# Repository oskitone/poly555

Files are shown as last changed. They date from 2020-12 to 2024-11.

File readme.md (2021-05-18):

# POLY555 Synth

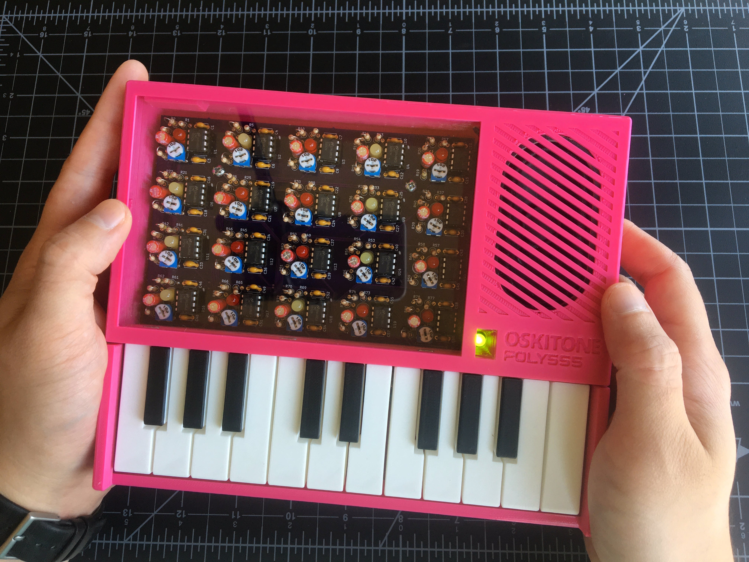
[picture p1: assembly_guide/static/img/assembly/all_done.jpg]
A finished POLY555


The POLY555 is a _polyphonic_, analog, square wave synth based on the _555_ timer chip.

**Demo:** [https://vimeo.com/487720782](https://vimeo.com/487720782)<br />
**Purchase a kit:** [https://www.oskitone.com/product/poly555-synth-diy-kit](https://www.oskitone.com/product/poly555-synth-diy-kit)<br />
**Assembly Guide:** [https://oskitone.github.io/poly555/](https://oskitone.github.io/poly555/)<br />
**Blog post:** [https://blog.tommy.sh/posts/poly555-synth/](https://blog.tommy.sh/posts/poly555-synth/)

## Code

This repo contains:

1. The [kicad](kicad) project for the PCB
2. The [openscad](openscad) code for generating the models for 3D-printing
3. The [assembly_guide](assembly_guide) code for, you guessed it, generating the [Assembly Guide](https://oskitone.github.io/poly555/)

### License

Designed by Oskitone. Please support future synth projects by purchasing from [Oskitone](https://www.oskitone.com/).

Creative Commons Attribution/Share-Alike, all text above must be included in any redistribution. See license.txt for additional details.

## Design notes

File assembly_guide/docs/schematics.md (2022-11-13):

---
id: schematics
title: "Appendix: Schematics"
description: POLY555 electronics schematic
sidebar_label: Schematics
image: /img/schematics/poly_555.svg
---

POLY555 schematic

555 sheet schematic

Enumerated sheet schematics here: [https://github.com/oskitone/poly555](https://github.com/oskitone/poly555)

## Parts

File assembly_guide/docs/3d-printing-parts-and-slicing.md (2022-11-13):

---
id: 3d-printing-parts-and-slicing
title: 3D-Printing Parts and Slicing
sidebar_label: Parts and Slicing
description: Downloading and slicing the POLY555 parts for your 3D-printer
image: /img/assembly/all_done.jpg
---

:::note
If you bought the kit with the 3D-printed parts included, you can skip this part!
:::

## Download 3D Models

The POLY555's models are hosted on Thingiverse at [https://www.thingiverse.com/thing:4676728/files](https://www.thingiverse.com/thing:4676728/files).

Download them and then come on back here!

## Parts

There are five parts you'll need to print:

1. **Enclosure top:**
   The enclosure's top with window, speaker grill, LED cavity, and branding engraving
2. **Enclosure bottom:**
   The biggest piece! The PCB mounts onto this.
3. **Keys:**
   The piano keys. This needs to be printed in two colors, see below.
4. **Mounting rail:**
   This mounting rail piece will sit between the PCB and the keys.
5. **Volume wheel:**
   And the volume wheel fits onto a potentiometer and is exposed on the enclosure's side.

### Reduced test case

Wondering what that sixth file called "reduced_test_case" is for?

This is optional but helpful for confirming your printer and slicer will be able to print the full POLY555 and have it assemble as expected. It takes about 30min.

If the test case's two pieces are difficult to fit together successfully after printing, revisit your slicer settings and ensure the printer is calibrated. Repeat until successful.

## Slicing recommendations

| Piece | Layer height | Color change | Print time |
| --- | --- | --- | --- |
| **Enclosure top** | .2mm | n/a | 4hr |
| **Enclosure bottom** | .2mm | n/a | 8hr 30min  |
| **Keys** | .2mm | 16.8mm | 7hr |
| **Mounting rail** | .2mm | n/a | 30min |
| **Volume wheel** | .2mm | n/a | 10min |

**Notes:**

- Models assume Fused Deposition Modeling with a standard .4mm nozzle. Using a bigger nozzle will likely result in a loss of detail and possibly missing internal walls.
- You may find the bottoms of the keys stick together because the plastic has expanded too far into the gap between them. See if your slicer has a setting called something like ["Elephant foot compensation"](https://help.prusa3d.com/en/article/elephant-foot-compensation_114487). Otherwise you'll need to carefully cut off the excess plastic with a utility knife.
- The 3D-printed parts were designed using PLA. Other filament types like ABS are not recommended and will likely have fit or tolerance issues. (If you find that you need to drill or file your prints, that's a good sign there'll be other problems too.)
- Any supports the models need they'll already have, they'll already be rotated to the correct orientation for printing, and they shouldn't need brims. Brims on the keys, in fact, could cause warping on removal.
- The enclosure pieces are big and may warp off the bed plate without good adhesion. I tend to use a lot of glue on the bed and stay away from plastics that shrink. _Watch the first couple layers of these while printing, especially around the text engravings -- if you see bad adhesion, stop the print to remedy the situation and start again._
- If the prints aren't fitting together well, check to see that the corners aren't bulging. We should see clean, sharp edges on the mounting rail and the keys' mount. See if your slicer has settings for "coasting" or "linear advance."

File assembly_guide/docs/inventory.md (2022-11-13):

---
id: inventory
title: Inventory
sidebar_label: Inventory
description: Inventory for the POLY555 kit and what you'll need to assemble it
image: /img/kit.jpg
---

## What's Included in the Kit

:::note
While the values of the components and the layout of the PCB won't change, they may vary in appearance (ie, changing the brand of caps, different color/silkscreen PCB, wire colors, etc), so your kit's parts may look slightly different than what's pictured throughout the guide. That's just fine! Everything will work the same.
:::

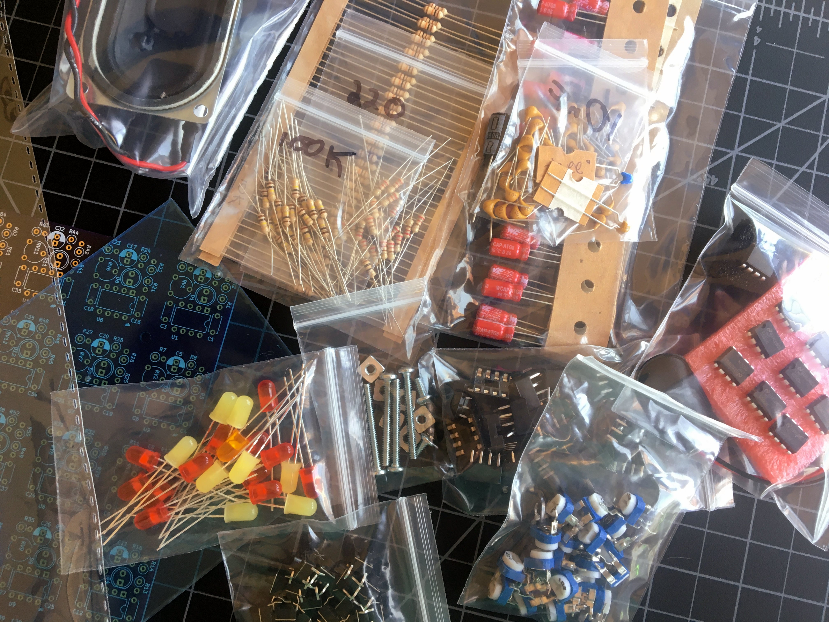
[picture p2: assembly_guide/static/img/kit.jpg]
The POLY555 DIY Kit


- **Printed circuit board (PCB):** 1
- **Plexiglass window pane:** 1
- **Electronics components:** 255 pieces total!
  - **9v snap, chips, switch:** 24
  - **Capacitors:** 64
  - **IC chip sockets:** 21
  - **LEDs:** 3 colors, 21 total
  - **Resistors:** 83
  - **Speaker:** 1
  - **Tactile switches:** 20
  - **Trim potentiometers:** 21
- **Nuts and bolts:** 12

### Not Using the Kit?

If you're going the full open-source route and gathering all the parts by yourself, head over to the [POLY555 from Scratch](poly555-from-scratch.md) appendix, then come back here when you're done.

## What You'll Need

You'll need the following tools to assemble your POLY555:

### Required

- Soldering iron and solder for electronics
- Wire stripper or cutters
- Philips and flathead screwdrivers
- Chromatic instrument tuner, phone app, or an [online tuner](https://www.google.com/search?q=online+instrument+tuner)
- Utility knife
- School glue
- 9v battery

### Recommended

- Multimeter for debugging
- PCB vice or “helping hands” holder
- “Solder sucker” or desoldering braid
- Tweezers or “dentist’s tools” for working with small components
- Windex
- Patience, patience, patience

:::tip
Give yourself plenty of time to put this together, at least 5 hours. There are a lot of components and things to solder!

I like to spread it out throughout the day and take lots of breaks!
:::

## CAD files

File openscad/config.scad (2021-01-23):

SHOW_ENCLOSURE_BOTTOM = true;
SHOW_BATTERY = true;
SHOW_SPEAKER = true;
SHOW_SWITCH = true;
SHOW_PCB = true;
SHOW_VOLUME_WHEEL = true;
SHOW_MOUNTING_RAIL = true;
SHOW_KEYS = true;
SHOW_ENCLOSURE_TOP = true;
SHOW_WINDOW_PANE = false;
SHOW_PENCIL_STAND_PENCIL = false;

USE_PENCIL_STAND_DISPLAY_ANGLE = false;

ANIMATE_VISUALIZED_PLASTIC_TOLERANCE_WEIGHT = false;

QUICK_PREVIEW = true;
CROSS_SECTION = undef;
ECHO_DIMENSIONS = true;
FLIP_VERTICALLY = false;
REDUCED_TEST_CASE = false;

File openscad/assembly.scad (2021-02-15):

include <config.scad>;
include <lib/values.scad>;

use <lib/basic_shapes.scad>;
use <lib/battery.scad>;
use <lib/breakaway_support.scad>;
use <lib/diagonal_grill.scad>;
use <lib/enclosure.scad>;
use <lib/engraving.scad>;
use <lib/keys.scad>;
use <lib/mount_stilt.scad>;
use <lib/mounting_rail.scad>;
use <lib/nut_lock.scad>;
use <lib/pcb.scad>;
use <lib/pencil_stand.scad>;
use <lib/speaker.scad>;
use <lib/supportless_screw_cavity.scad>;
use <lib/switch.scad>;
use <lib/utils.scad>;

module assembly(
    key_gutter = 1,
    accidental_key_recession = 2,
    natural_key_exposed_height = 3,
    accidental_key_extra_height = 3,

    enclosure_wall = 2.4,
    enclosure_floor_ceiling = 1.8,
    enclosure_inner_wall = 1.2,
    enclosure_minimum_wall = .6,
    enclosure_fillet = 2,
    enclosure_rounding = 24,
    enclosure_lip = .8,
    enclosure_lip_height = LIP_BOX_DEFAULT_LIP_HEIGHT,
    enclosure_lip_clearance = .2,

    engraving_depth = .8,
    engraving_chamfer = .2,

    components_to_window_clearance = 2,
    speaker_to_battery_clearance = .4,
    exposed_switch_clearance = 1,
    exposed_screw_head_clearance = .4,

    mount_length = 6,
    cantilever_length = 3,
    cantilever_mount_height = 3,
    cantilever_height = 1,

    tolerance = .1,

    keys_count = 20,
    starting_natural_key_index = 3,
    key_travel = 2, // TODO: refine

    // Adjust from 0 to 1 to see possible plastic dimensions from manufacturer
    visualized_plastic_tolerance_weight = .5,
    animate_visualized_plastic_tolerance_weight = false,

    volume_wheel_exposure = 1,
    volume_wheel_cap_height = 1,
    volume_wheel_grip_size = 1.5,
    volume_wheel_vertical_clearance = .4,
    volume_wheel_brace_clearance = .2,

    pencil_stand_display_angle = 65,
    use_pencil_stand_display_angle = true,

    show_enclosure_bottom = true,
    show_battery = true,
    show_speaker = true,
    show_switch = true,
    show_pcb = true,
    show_volume_wheel = true,
    show_mounting_rail = true,
    show_keys = true,
    show_enclosure_top = true,
    show_window_pane = false,
    show_pencil_stand_pencil = true,

    enclosure_color = undef,
    enclosure_opacity = .75,
    pcb_color = "purple",
    pcb_opacity = .75,
    natural_key_color = "white",
    accidental_key_color = "black",
    key_opacity = .75,

    quick_preview = false,
    cross_section = undef,
    echo_dimensions = true,
    flip_vertically = false,
    reduced_test_case = false
) {
    e = 0.0145;
    plot = PCB_BUTTONS[1][0] - PCB_BUTTONS[0][0];
    enclosure_gutter = mount_length;

    keys_back_gutter = tolerance * 2;
    cantilever_recession = cantilever_length - keys_back_gutter;

    natural_key_width = plot * 2 - key_gutter;
    natural_key_length = natural_key_width * 4
        - (cantilever_length - cantilever_recession) - mount_length;

    mount_width= get_keys_total_width(
        count = keys_count,
        starting_note_index =
            get_starting_note_index(starting_natural_key_index),
        natural_width = natural_key_width,
        gutter = key_gutter
    );
    mount_height = BUTTON_HEIGHT;

    mounted_keys_total_length = natural_key_length
        + (cantilever_length - cantilever_recession)
        + mount_length;

    keys_mount_end_on_pcb = BOTTOM_MOUNTED_PCB_HOLES[0][1] +  mount_length / 2;
    keys_y_over_pcb = mounted_keys_total_length - keys_mount_end_on_pcb;
    keys_from_pcb_x_offset = PCB_BUTTONS[0][0] - BUTTON_WIDTH / 2 - plot + key_gutter / 2;
    keys_cavity_length = natural_key_length + key_gutter + keys_back_gutter;
    keys_and_bumper_cavity_length = keys_cavity_length + enclosure_gutter
        - key_gutter;

    mount_hole_xs = [
        BOTTOM_MOUNTED_PCB_HOLES[0][0] - keys_from_pcb_x_offset,
        BOTTOM_MOUNTED_PCB_HOLES[1][0] - keys_from_pcb_x_offset,
        BOTTOM_MOUNTED_PCB_HOLES[2][0] - keys_from_pcb_x_offset,
        BOTTOM_MOUNTED_PCB_HOLES[3][0] - keys_from_pcb_x_offset,
    ];

    window_y_extension = PCB_COMPONENTS_Y - keys_mount_end_on_pcb;
    pcb_x = enclosure_gutter - keys_from_pcb_x_offset;
    pcb_y = mounted_keys_total_length - keys_mount_end_on_pcb + enclosure_gutter;
    pcb_z = enclosure_floor_ceiling + max(
        MOUNT_STILT_MINIMUM_HEIGHT,
        SWITCH_BASE_HEIGHT + SWITCH_ACTUATOR_HEIGHT
            - enclosure_floor_ceiling + exposed_switch_clearance
    );
    pcb_stilt_height = pcb_z - enclosure_floor_ceiling;

    enclosure_width = reduced_test_case
        ? 30 // arbitrary
        : enclosure_gutter * 2 + mount_width;
    enclosure_length = pcb_y + keys_mount_end_on_pcb
        + PCB_COMPONENTS_LENGTH + window_y_extension * 2
        + enclosure_gutter;

    enclosure_height = enclosure_floor_ceiling * 2 + max(
        pcb_stilt_height + PCB_HEIGHT + PCB_COMPONENTS_HEIGHT
            + WINDOW_PANE_HEIGHT + components_to_window_clearance,
        SPEAKER_HEIGHT - SPEAKER_MAGNET_HEIGHT + BATTERY_HEIGHT
            + speaker_to_battery_clearance
    );
    enclosure_bottom_height =
        get_volume_wheel_z(
            cap_height = volume_wheel_cap_height,
            pcb_z = pcb_z,
            pcb_height = PCB_HEIGHT,
            pot_height = POT_HEIGHT,
            head_height = TRIMPOT_KNOB_HEAD_HEIGHT
        )
        + get_volume_wheel_total_height(volume_wheel_cap_height)
        + volume_wheel_vertical_clearance;
    enclosure_top_height = enclosure_height - enclosure_bottom_height;

    key_height = enclosure_height - pcb_stilt_height - enclosure_floor_ceiling
        - PCB_HEIGHT - mount_height - accidental_key_extra_height
        - accidental_key_recession;
    keys_x = pcb_x + keys_from_pcb_x_offset;
    assert(keys_x == enclosure_gutter, "keys_x should equal enclosure_gutter");
    keys_y = pcb_y
        - natural_key_length
        - (cantilever_length - cantilever_recession)
        + keys_mount_end_on_pcb
        - mount_length;
    keys_z = pcb_z + PCB_HEIGHT + BUTTON_HEIGHT;
    key_mounting_rail_x = enclosure_wall + tolerance * 2;
    key_mounting_rail_y = pcb_y + keys_mount_end_on_pcb - mount_length;

    battery_x = enclosure_width - BATTERY_WIDTH - enclosure_wall - tolerance;
    battery_y = enclosure_length - enclosure_wall - BATTERY_LENGTH - tolerance;

    switch_x = pcb_x + PCB_SWITCH_X;
    switch_y = pcb_y + PCB_SWITCH_Y;
    switch_z = pcb_z;
    switch_exposure_height = switch_z - SWITCH_BASE_HEIGHT;

    window_and_side_panel_gutter = enclosure_gutter - key_gutter;

    window_cavity_width = PCB_COMPONENTS_WIDTH +
        ((pcb_x + PCB_COMPONENTS_X) - window_and_side_panel_gutter) * 2;
    window_cavity_length = PCB_COMPONENTS_LENGTH + window_y_extension * 2;
    window_cavity_y = pcb_y + PCB_COMPONENTS_Y - window_y_extension;

    // Pane dimensions are average between +/- PLASTICS_TOLERANCE
    window_pane_x = enclosure_wall + tolerance;
    window_pane_y = pcb_y + keys_mount_end_on_pcb - tolerance
        - (mount_length - PCB_MOUNT_HOLE_DIAMETER) / 2;
    window_pane_z = enclosure_height - enclosure_floor_ceiling
        - WINDOW_PANE_HEIGHT;
    window_pane_max_width = window_cavity_width + window_pane_x * 2;
    window_pane_width = window_pane_max_width - PLASTICS_TOLERANCE;
    window_pane_max_length = enclosure_length - enclosure_wall - window_pane_y
        - tolerance;
    window_pane_length = window_pane_max_length - PLASTICS_TOLERANCE;

    side_panel_width = enclosure_width
        - window_and_side_panel_gutter * 3
        - window_cavity_width;
    side_panel_x = enclosure_width - side_panel_width - window_and_side_panel_gutter;
    side_panel_y = key_mounting_rail_y + mount_length;
    side_panel_length = enclosure_length - enclosure_gutter - side_panel_y;

    volume_wheel_diameter = (enclosure_width - (pcb_x + PCB_VOLUME_WHEEL_X)) * 2;

    branding_length = ((pcb_y + PCB_LED_Y) - side_panel_y) * 2;
    speaker_grill_length = side_panel_length - branding_length - enclosure_gutter;
    speaker_grill_y = side_panel_y + side_panel_length - speaker_grill_length;

    speaker_x = side_panel_x + side_panel_width / 2;
    speaker_y = speaker_grill_y + (speaker_grill_length - SPEAKER_LENGTH) / 2
        + SPEAKER_LENGTH / 2;
    speaker_z = enclosure_height - enclosure_floor_ceiling - SPEAKER_HEIGHT;

    aligner_width = enclosure_inner_wall;

    if (echo_dimensions) {
        echo(
            "Enclosure dimensions",
            [enclosure_width, enclosure_length, enclosure_height]
        );
        echo(
            "Window cavity dimensions",
            [window_cavity_width, window_cavity_length]
        );
        echo(
            "Window pane dimensions",
            [window_pane_width, window_pane_length]
        );
    }

    module _keys_hitch_endstop(
        clearance = .4,
        coverage = 2,
        bar_height = 1,

        cavity = false,
        cavity_key_floor = 2,
        cavity_clearance = tolerance * 4 // intentionally loose
    ) {
        xy = enclosure_wall - e;
        bar_z = keys_z + cavity_key_floor;
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

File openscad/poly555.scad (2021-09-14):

include <config.scad>;
include <lib/values.scad>;

use <lib/basic_shapes.scad>;
use <lib/battery.scad>;
use <lib/breakaway_support.scad>;
use <lib/diagonal_grill.scad>;
use <lib/enclosure.scad>;
use <lib/engraving.scad>;
use <lib/keys.scad>;
use <lib/mount_stilt.scad>;
use <lib/mounting_rail.scad>;
use <lib/nut_lock.scad>;
use <lib/pcb.scad>;
use <lib/pencil_stand.scad>;
use <lib/screw_head_exposures.scad>;
use <lib/speaker.scad>;
use <lib/switch.scad>;
use <lib/utils.scad>;

module poly555(
    key_gutter = 1,
    accidental_key_recession = 2,
    natural_key_exposed_height = 3,
    accidental_key_extra_height = 3,

    enclosure_wall = 2.4,
    enclosure_floor_ceiling = 1.8,
    enclosure_inner_wall = 1.2,
    enclosure_minimum_wall = .6,
    enclosure_fillet = 2,
    enclosure_rounding = 24,
    enclosure_lip = .8,
    enclosure_lip_height = LIP_BOX_DEFAULT_LIP_HEIGHT,
    enclosure_lip_clearance = .2,

    engraving_depth = .8,
    engraving_chamfer = .2,

    components_to_window_clearance = 2,
    speaker_to_battery_clearance = .4,
    exposed_switch_clearance = 1,
    exposed_screw_head_clearance = .4,

    mount_length = 6,
    cantilever_length = 3,
    cantilever_mount_height = 3,
    cantilever_height = 1,

    tolerance = .1,

    keys_count = 20,
    starting_natural_key_index = 3,
    key_travel = 2, // TODO: refine

    // Adjust from 0 to 1 to see possible plastic dimensions from manufacturer
    visualized_plastic_tolerance_weight = .5,
    animate_visualized_plastic_tolerance_weight = false,

    volume_wheel_exposure = 1,
    volume_wheel_cap_height = 1,
    volume_wheel_grip_size = 1.5,
    volume_wheel_vertical_clearance = .4,
    volume_wheel_brace_clearance = .2,

    pencil_stand_display_angle = 65,
    use_pencil_stand_display_angle = true,

    show_enclosure_bottom = true,
    show_battery = true,
    show_speaker = true,
    show_switch = true,
    show_pcb = true,
    show_volume_wheel = true,
    show_mounting_rail = true,
    show_keys = true,
    show_enclosure_top = true,
    show_window_pane = false,
    show_pencil_stand_pencil = true,

    enclosure_color = undef,
    enclosure_opacity = .75,
    pcb_color = "purple",
    pcb_opacity = .75,
    natural_key_color = "white",
    accidental_key_color = "black",
    key_opacity = .75,

    quick_preview = false,
    cross_section = undef,
    echo_dimensions = true,
    flip_vertically = false,
    reduced_test_case = false
) {
    e = 0.0145;
    plot = PCB_BUTTONS[1][0] - PCB_BUTTONS[0][0];
    enclosure_gutter = mount_length;

    keys_back_gutter = tolerance * 2;
    cantilever_recession = cantilever_length - keys_back_gutter;

    natural_key_width = plot * 2 - key_gutter;
    natural_key_length = natural_key_width * 4
        - (cantilever_length - cantilever_recession) - mount_length;

    mount_width= get_keys_total_width(
        count = keys_count,
        starting_note_index =
            get_starting_note_index(starting_natural_key_index),
        natural_width = natural_key_width,
        gutter = key_gutter
    );
    mount_height = BUTTON_HEIGHT;

    mounted_keys_total_length = natural_key_length
        + (cantilever_length - cantilever_recession)
        + mount_length;

    keys_mount_end_on_pcb = BOTTOM_MOUNTED_PCB_HOLES[0][1] +  mount_length / 2;
    keys_y_over_pcb = mounted_keys_total_length - keys_mount_end_on_pcb;
    keys_from_pcb_x_offset = PCB_BUTTONS[0][0] - BUTTON_WIDTH / 2 - plot + key_gutter / 2;
    keys_cavity_length = natural_key_length + key_gutter + keys_back_gutter;
    keys_and_bumper_cavity_length = keys_cavity_length + enclosure_gutter
        - key_gutter;

    mount_hole_xs = [
        BOTTOM_MOUNTED_PCB_HOLES[0][0] - keys_from_pcb_x_offset,
        BOTTOM_MOUNTED_PCB_HOLES[1][0] - keys_from_pcb_x_offset,
        BOTTOM_MOUNTED_PCB_HOLES[2][0] - keys_from_pcb_x_offset,
        BOTTOM_MOUNTED_PCB_HOLES[3][0] - keys_from_pcb_x_offset,
    ];

    window_y_extension = PCB_COMPONENTS_Y - keys_mount_end_on_pcb;
    pcb_x = enclosure_gutter - keys_from_pcb_x_offset;
    pcb_y = mounted_keys_total_length - keys_mount_end_on_pcb + enclosure_gutter;
    pcb_z = enclosure_floor_ceiling + max(
        MOUNT_STILT_MINIMUM_HEIGHT,
        SWITCH_BASE_HEIGHT + SWITCH_ACTUATOR_HEIGHT
            - enclosure_floor_ceiling + exposed_switch_clearance
    );
    pcb_stilt_height = pcb_z - enclosure_floor_ceiling;

    enclosure_width = reduced_test_case
        ? 30 // arbitrary
        : enclosure_gutter * 2 + mount_width;
    enclosure_length = pcb_y + keys_mount_end_on_pcb
        + PCB_COMPONENTS_LENGTH + window_y_extension * 2
        + enclosure_gutter;

    enclosure_height = enclosure_floor_ceiling * 2 + max(
        pcb_stilt_height + PCB_HEIGHT + PCB_COMPONENTS_HEIGHT
            + WINDOW_PANE_HEIGHT + components_to_window_clearance,
        SPEAKER_HEIGHT - SPEAKER_MAGNET_HEIGHT + BATTERY_HEIGHT
            + speaker_to_battery_clearance
    );
    enclosure_bottom_height =
        get_volume_wheel_z(
            cap_height = volume_wheel_cap_height,
            pcb_z = pcb_z,
            pcb_height = PCB_HEIGHT,
            pot_height = POT_HEIGHT,
            head_height = TRIMPOT_KNOB_HEAD_HEIGHT
        )
        + get_volume_wheel_total_height(volume_wheel_cap_height)
        + volume_wheel_vertical_clearance;
    enclosure_top_height = enclosure_height - enclosure_bottom_height;

    key_height = enclosure_height - pcb_stilt_height - enclosure_floor_ceiling
        - PCB_HEIGHT - mount_height - accidental_key_extra_height
        - accidental_key_recession;
    keys_x = pcb_x + keys_from_pcb_x_offset;
    assert(keys_x == enclosure_gutter, "keys_x should equal enclosure_gutter");
    keys_y = pcb_y
        - natural_key_length
        - (cantilever_length - cantilever_recession)
        + keys_mount_end_on_pcb
        - mount_length;
    keys_z = pcb_z + PCB_HEIGHT + BUTTON_HEIGHT;
    key_mounting_rail_x = enclosure_wall + tolerance * 2;
    key_mounting_rail_y = pcb_y + keys_mount_end_on_pcb - mount_length;

    battery_x = enclosure_width - BATTERY_WIDTH - enclosure_wall - tolerance;
    battery_y = enclosure_length - enclosure_wall - BATTERY_LENGTH - tolerance;

    switch_x = pcb_x + PCB_SWITCH_X;
    switch_y = pcb_y + PCB_SWITCH_Y;
    switch_z = pcb_z;
    switch_exposure_height = switch_z - SWITCH_BASE_HEIGHT;

    window_and_side_panel_gutter = enclosure_gutter - key_gutter;

    window_cavity_width = PCB_COMPONENTS_WIDTH +
        ((pcb_x + PCB_COMPONENTS_X) - window_and_side_panel_gutter) * 2;
    window_cavity_length = PCB_COMPONENTS_LENGTH + window_y_extension * 2;
    window_cavity_y = pcb_y + PCB_COMPONENTS_Y - window_y_extension;

    // Pane dimensions are average between +/- PLASTICS_TOLERANCE
    window_pane_x = enclosure_wall + tolerance;
    window_pane_y = pcb_y + keys_mount_end_on_pcb - tolerance
        - (mount_length - PCB_MOUNT_HOLE_DIAMETER) / 2;
    window_pane_z = enclosure_height - enclosure_floor_ceiling
        - WINDOW_PANE_HEIGHT;
    window_pane_max_width = window_cavity_width + window_pane_x * 2;
    window_pane_width = window_pane_max_width - PLASTICS_TOLERANCE;
    window_pane_max_length = enclosure_length - enclosure_wall - window_pane_y
        - tolerance;
    window_pane_length = window_pane_max_length - PLASTICS_TOLERANCE;

    side_panel_width = enclosure_width
        - window_and_side_panel_gutter * 3
        - window_cavity_width;
    side_panel_x = enclosure_width - side_panel_width - window_and_side_panel_gutter;
    side_panel_y = key_mounting_rail_y + mount_length;
    side_panel_length = enclosure_length - enclosure_gutter - side_panel_y;

    volume_wheel_diameter = (enclosure_width - (pcb_x + PCB_VOLUME_WHEEL_X)) * 2;

    branding_length = ((pcb_y + PCB_LED_Y) - side_panel_y) * 2;
    speaker_grill_length = side_panel_length - branding_length - enclosure_gutter;
    speaker_grill_y = side_panel_y + side_panel_length - speaker_grill_length;

    speaker_x = side_panel_x + side_panel_width / 2;
    speaker_y = speaker_grill_y + (speaker_grill_length - SPEAKER_LENGTH) / 2
        + SPEAKER_LENGTH / 2;
    speaker_z = enclosure_height - enclosure_floor_ceiling - SPEAKER_HEIGHT;

    aligner_width = enclosure_inner_wall;

    if (echo_dimensions) {
        echo(
            "Enclosure dimensions",
            [enclosure_width, enclosure_length, enclosure_height]
        );
        echo(
            "Window cavity dimensions",
            [window_cavity_width, window_cavity_length]
        );
        echo(
            "Window pane dimensions",
            [window_pane_width, window_pane_length]
        );
    }

    module _keys_hitch_endstop(
        clearance = .4,
        coverage = 2,
        bar_height = 1,

        cavity = false,
        cavity_key_floor = 2,
        cavity_clearance = tolerance * 4 // intentionally loose
    ) {
        xy = enclosure_wall - e;
        bar_z = keys_z + cavity_key_floor;
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

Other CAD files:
openscad/tests.scad

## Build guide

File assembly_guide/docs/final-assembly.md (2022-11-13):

---
id: final-assembly
title: Final Assembly
sidebar_label: Final Assembly
description: How to do final assembly of the POLY555
image: /img/assembly/hitch.jpg
---

Almost there! Let's finish up.

:::caution
Take your time here. If the 3D-printed parts aren't fitting well together, don't force them -- you may accidentally break something. Instead, check for leftover support material that needs to be removed and gently carve it away with a utility knife.
:::

## Steps

1. **Affix PCB**
   1. Slide 2 **square nuts** into the back PCB posts on the enclosure bottom half.
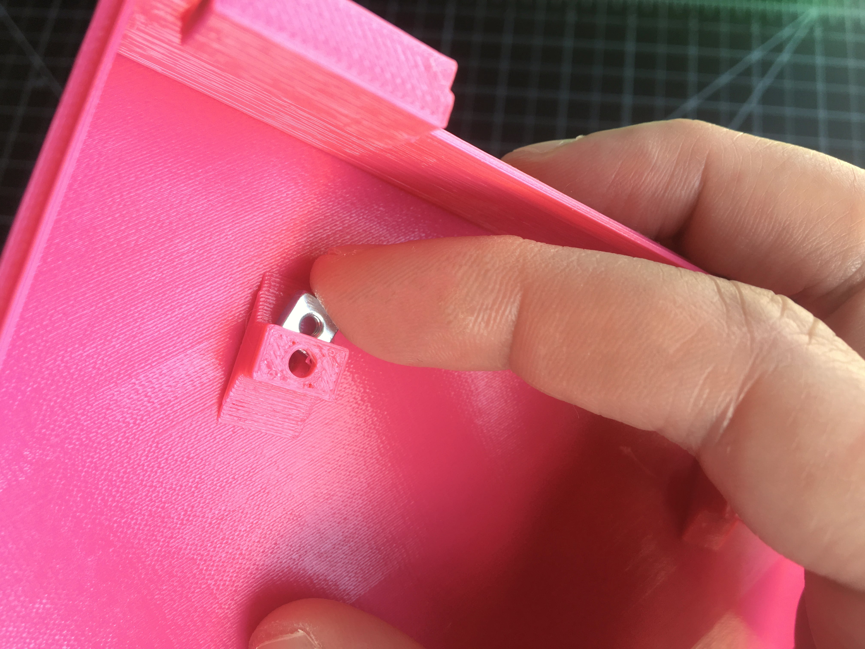
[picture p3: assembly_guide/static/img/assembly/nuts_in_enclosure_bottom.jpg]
Two square nuts in their posts
      
   2. Place the **finished PCB** into the enclosure bottom half, fitting the switch into its cavity.
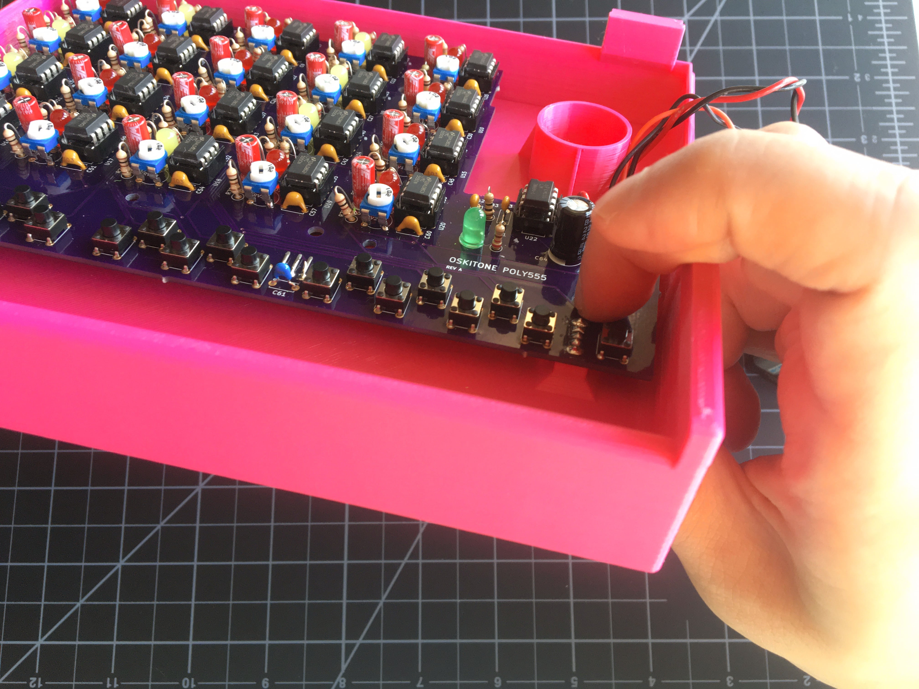
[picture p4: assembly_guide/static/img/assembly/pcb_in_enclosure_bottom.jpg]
Placing the PCB into enclosure bottom
      
   3. Slide **9v battery** into its space behind the speaker. It will be a tight fit.
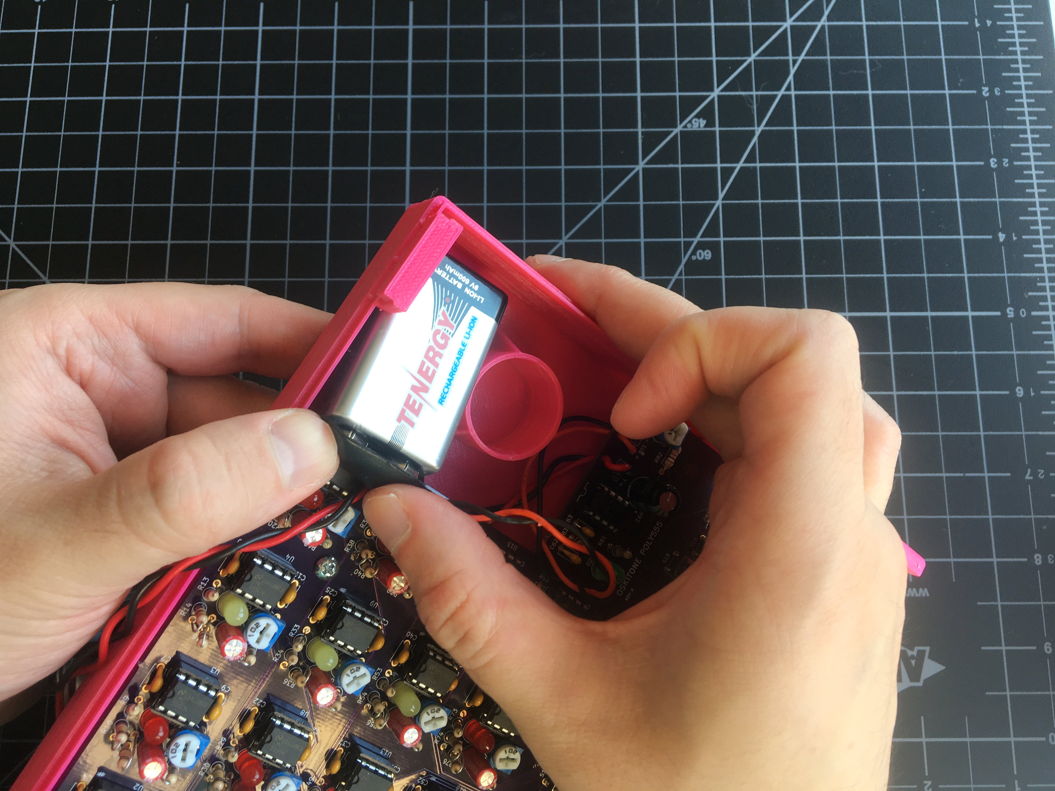
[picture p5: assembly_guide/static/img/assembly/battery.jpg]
9v battery
      
   4. Fit **speaker** into its container ring above battery. Try to hide any excess wire from the speaker under the PCB.
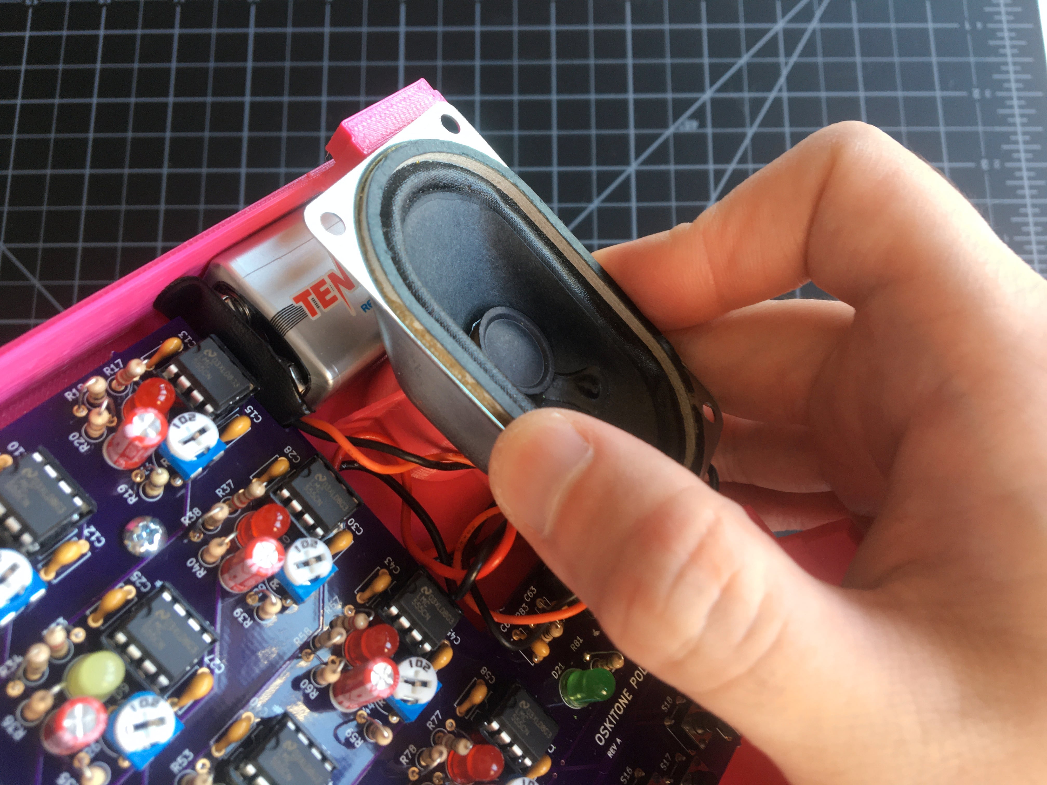
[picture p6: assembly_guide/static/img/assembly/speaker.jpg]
Pressing the speaker into its container
      
   5. Secure PCB into place with 2 **1/4" screws**. Don't overtighten!
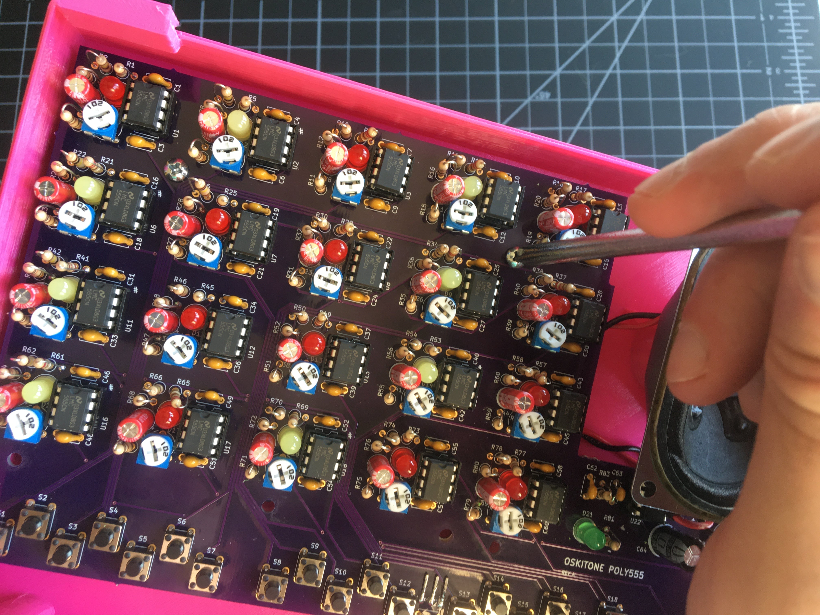
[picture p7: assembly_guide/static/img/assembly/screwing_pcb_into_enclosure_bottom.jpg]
Securing the PCB with screws
      
   6. Fit **volume wheel** onto **RV21**, matching its cavity to the trim pot's shape. As long as it's able to turn the underlying pot, it's okay if it's a little loose &mdash; it'll get held in place by the **enclosure top**.
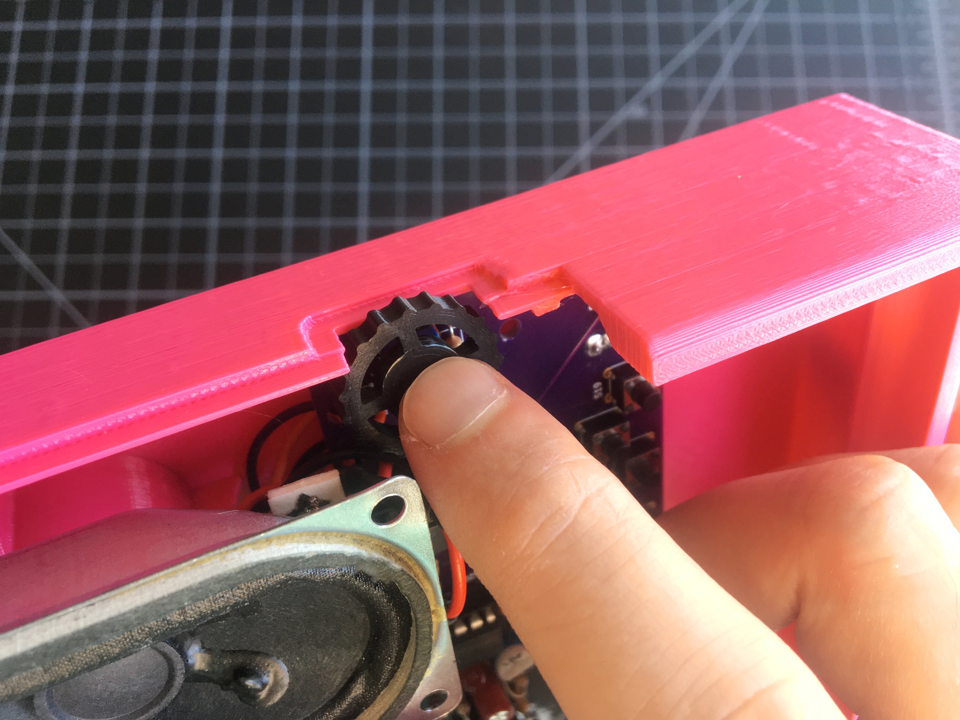
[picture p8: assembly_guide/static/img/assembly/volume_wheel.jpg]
Adding a volume wheel to the trim pot
      
2. **Add keys**
   1. Place **mounting rail** onto PCB, aligning its holes to the screw holes below.
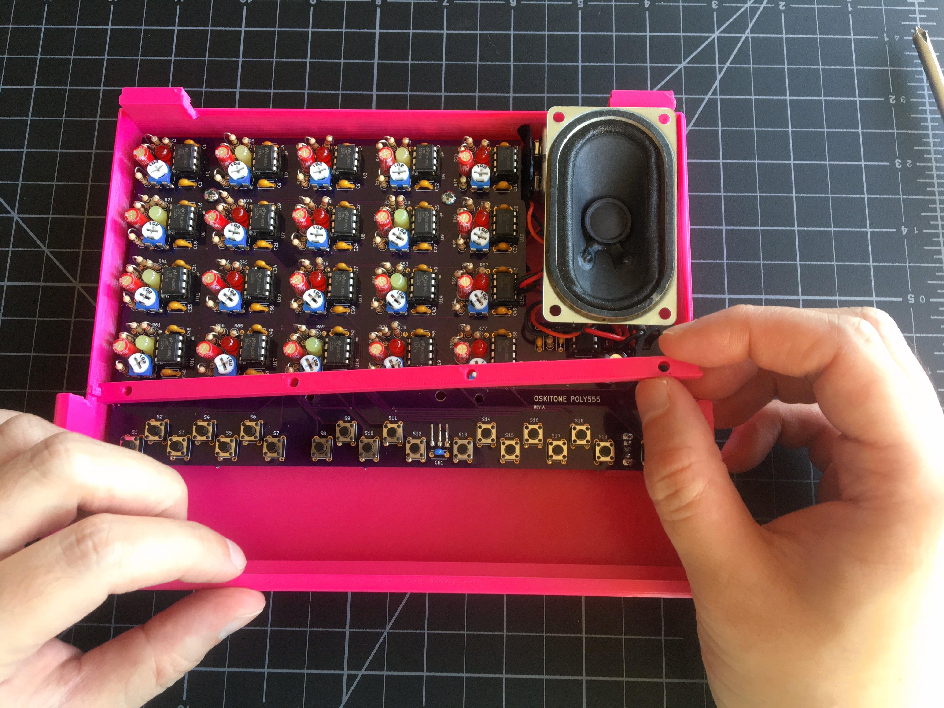
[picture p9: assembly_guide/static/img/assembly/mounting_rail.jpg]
Adding the mounting rail
      
   2. Place **keys** onto **mounting rail**.
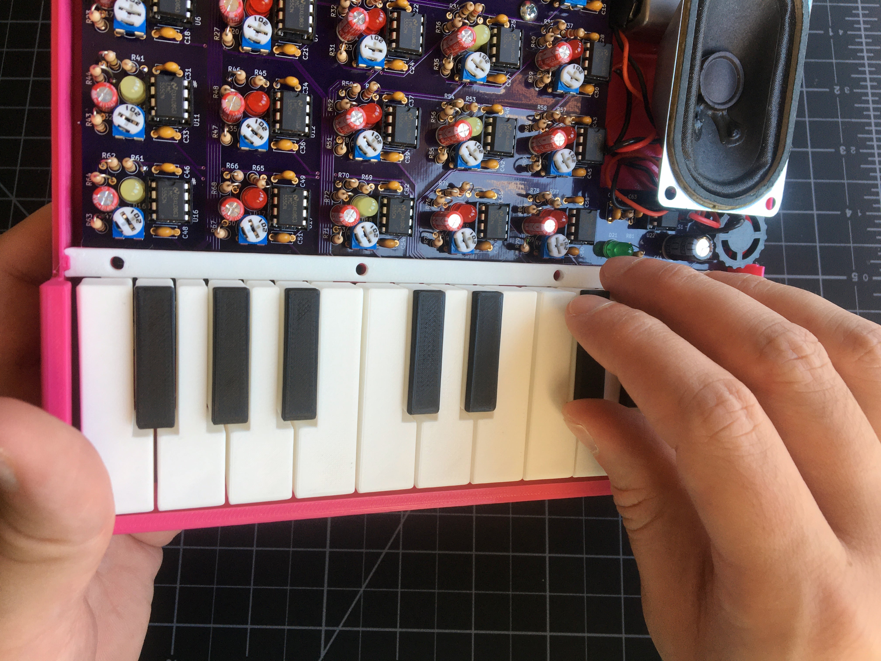
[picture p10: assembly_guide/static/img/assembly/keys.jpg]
Placing the keys onto mounting rail
      
3. **Finish enclosure**
   1. Insert 4 **square nuts** into the nut locks on the **enclosure top**. A small dab of glue here on each is optional but will help hold the nut in place the next time you disassemble.
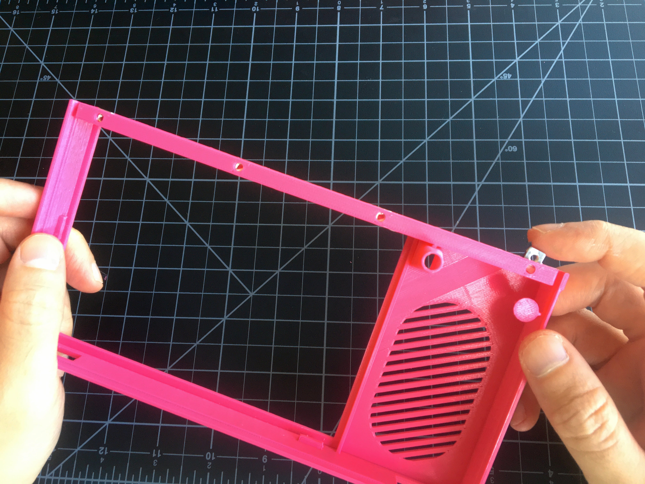
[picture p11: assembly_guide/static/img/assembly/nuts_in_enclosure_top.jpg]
Inserting square nuts
      
   2. Remove protective film from **plexiglass window pane** and fit it into the **enclosure top**.
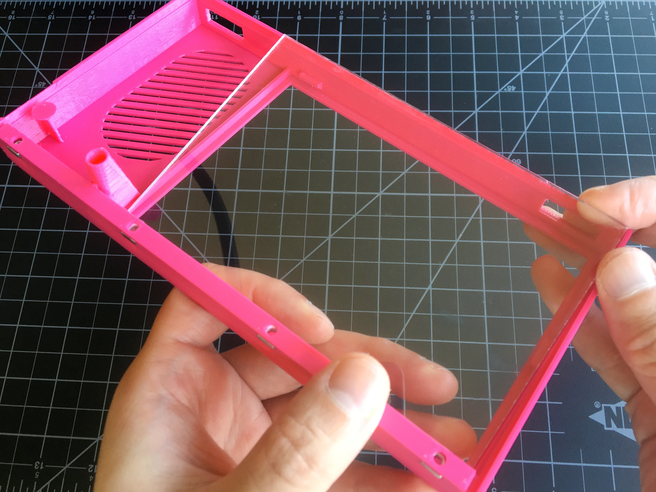
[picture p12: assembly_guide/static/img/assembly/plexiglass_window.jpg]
Adding the plexiglass window pane
      
      - It _will_ fit but may be tight. If you're worried about breaking the **enclosure top**, you can use a utility knife to carefully trim down the two holder tabs to give the **plexiglass window pane** more room.
      - Alternatively, if it's too loose, let a line of glue dry in the long cavity under the nuts. Repeat until the fit is snug.
   3. We're about to lock it up, so now's a good time to make sure your POLY555 is fully [tuned](tuning.md) and has a good battery. Oh, clean any smudges off the inside window now too.
   4. Gently align the **two enclosure halves**, fitting the back hitches on the bottom into their matching cavities on the top.
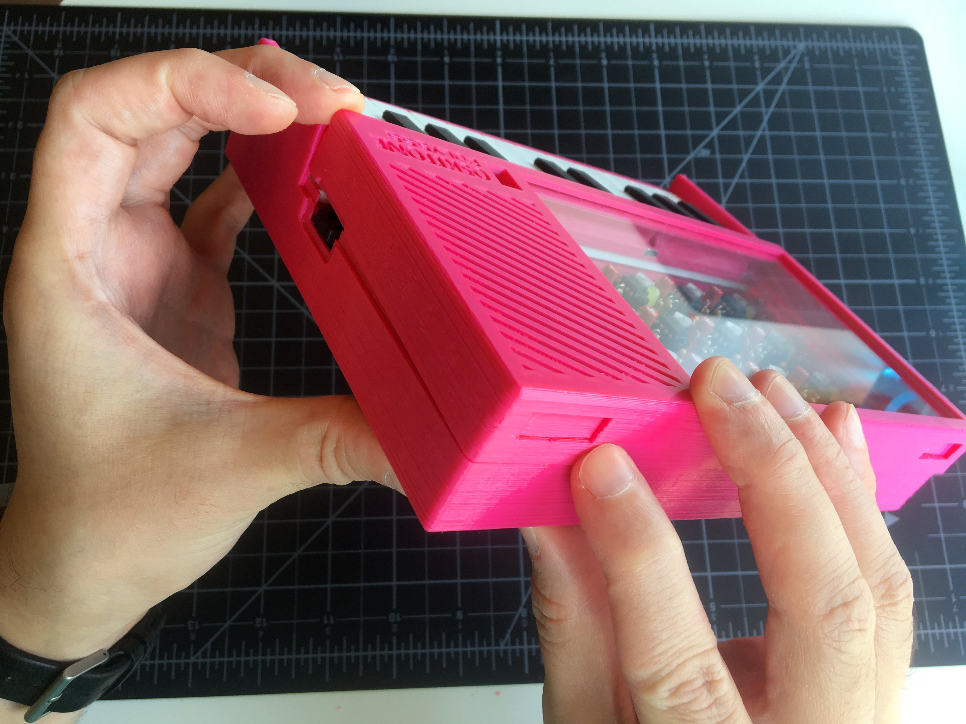
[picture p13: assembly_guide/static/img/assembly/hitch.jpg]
The enclosure bottom's hitches fitting into their cavities on the enclosure top
      
   5. Srew 4 **1" screws** into the four mounting rail holes on the bottom of the enclosure. Don't overtighten!
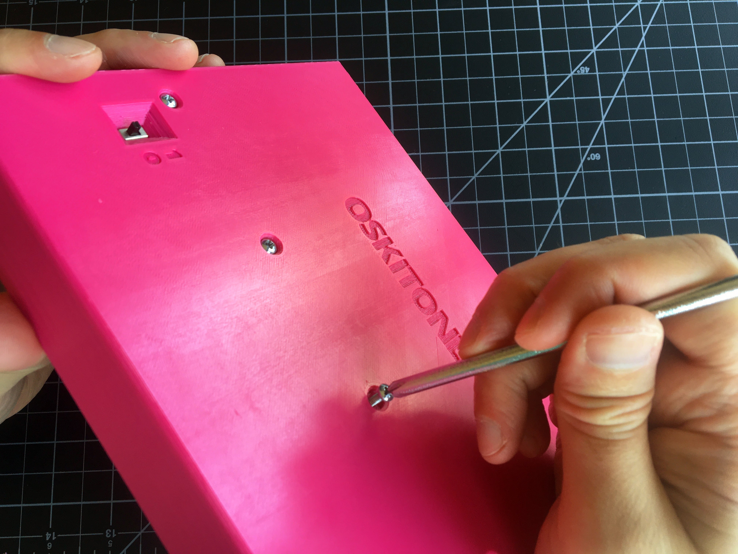
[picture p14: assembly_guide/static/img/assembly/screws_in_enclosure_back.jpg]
Screwing the two enclosure halves together from the bottom
      

## All Done!

A fully assembled POLY555

You’re done!!

Take a selfie with your brand new and very incredible POLY555 synthesizer. Feel good! You're the best!!

### Feedback

When you can, please [let me know](https://www.oskitone.com/contact) how it went for you:

- What did you like? Did you have fun?!
- Not including printing time, about how long did it take?
- Were there any parts missing or damaged?
- Any problems encountered with the instructions?
- Is there anything you'd change about the POLY555 itself?

I act and rely on customers' feedback to make future kits even better. Thank you so much!

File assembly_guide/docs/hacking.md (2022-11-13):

---
id: hacking
title: "Appendix: Hacking"
sidebar_label: Hacking
description: Hacking ideas for the POLY555
image: /img/hacking/gain-cap.jpg
---

:::warning
Do these at your own risk, hacker! You could very well break your POLY555!
:::

Your POLY555 can be hacked! Here are some ideas:

- You know the timers are tuned with their trimpots, but **how can we make them a different octave?** Try swapping their 4.7uF cap out to a higher value, maybe 10uF — higher values = lower frequency. You’ll probably want to play with the 100ohm resistor too; it sums with the trimpot and provides a “ceiling” that prevents you from tuning too high. Google the frequency formula for a 555 astable with 50/50 duty cycle for the math on how it all works.
- If you have a switching audio jack, **you could rig up an audio output** that’s separate from the speaker. Good luck on mounting it inside the enclosure, though; there's not a ton of spare room!
- **Want more volume?**
  - According to the [LM386 datasheet](https://www.ti.com/lit/ds/symlink/lm386.pdf) it has a default gain of 20 (26 dB), but, "if a capacitor is put from pin 1 to 8... the gain will go up to 200 (46 dB)".
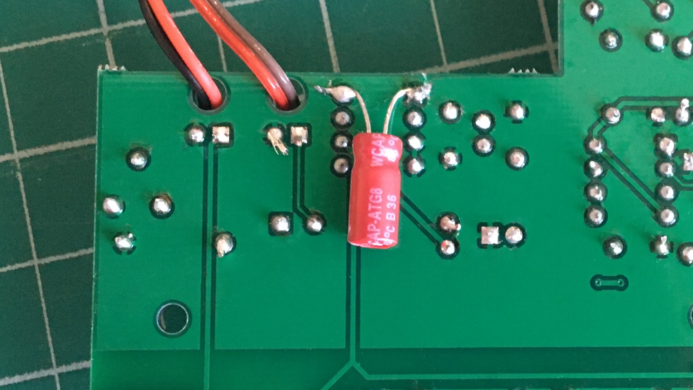
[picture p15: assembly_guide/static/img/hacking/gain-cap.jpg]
Amp gain cap
  - If your kit came with a spare 4.7uF capacitor, try that or any similar value. 
  - The 9.2.2 schematic in the datasheet has the cap's positive lead on pin 1, but polarity seems to not matter much in practice.

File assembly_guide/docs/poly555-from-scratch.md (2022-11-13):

---
id: poly555-from-scratch
title: "Appendix: POLY555 from Scratch"
description: BOM and sourcing advice for making the POLY555 "from scratch"
sidebar_label: POLY555 from Scratch
image: /img/schematics/poly_555.svg
---

:::note
This appendix is for folks making their POLY555 from scratch without buying the [kit](https://www.oskitone.com/product/poly555-synth-diy-kit).
:::

:::caution under construction
More so than the other parts of the assembly guide, _this_ part is especially a work-in-progress.
:::

## BOM

### Electronics

:::note
Some components may have a different designation in Kicad's BOM.
:::

| Designator | Package | Quantity | Designation |
| --- | --- | --- | --- |
| BT1 | PinHeader 1x02_P2.54mm Vertical | 1 | 9v snap |
| C59, C56, C53, C50, C47, C44, C41, C38, C35, C32, C29, C26, C23, C20, C17, C14, C11, C8, C5, C2 | CP_Radial D5.0mm_P2.00mm | 20 | 4.7uF |
| C60, C3, C6, C9, C12, C15, C18, C21, C24, C27, C30, C33, C36, C39, C42, C45, C48, C51, C54, C57 | C_Disc D5.0mm_W2.5mm_P5.00mm | 20 | 10nF |
| C61 | C_Disc D5.0mm_W2.5mm_P5.00mm | 1 | .22uF |
| C62, C1, C4, C7, C10, C13, C16, C19, C22, C25, C28, C31, C34, C37, C40, C43, C46, C49, C52, C55, C58 | C_Disc D5.0mm_W2.5mm_P5.00mm | 21 | .1uF |
| C63 | C_Disc D5.0mm_W2.5mm_P5.00mm | 1 | 47nF |
| C64 | CP_Radial D8.0mm_P3.50mm | 1 | 220uF |
| D21, D1, D2, D3, D4, D5, D6, D7, D8, D9, D10, D11, D12, D13, D14, D15, D16, D17, D18, D19, D20 | LED\_ D5.0mm | 21 \* | LED |
| LS1 | Speaker | 1 | SC700208 |
| R2, R6, R10, R14, R18, R22, R26, R30, R34, R38, R42, R46, R50, R54, R58, R62, R66, R70, R74, R78 | Resistor L6.3mm_D2.5mm | 20 | 100k |
| R4, R8, R12, R16, R20, R24, R28, R32, R36, R40, R44, R48, R52, R56, R60, R64, R68, R72, R76, R80 | Resistor L6.3mm_D2.5mm | 20 | 10k |
| R79, R75, R71, R67, R63, R59, R55, R51, R47, R43, R39, R35, R31, R27, R23, R19, R15, R11, R7, R3, R82 | Resistor L6.3mm_D2.5mm | 21 | 100 |
| R81, R1, R5, R9, R13, R17, R21, R25, R29, R33, R37, R41, R45, R49, R53, R57, R61, R65, R69, R73, R77 | Resistor L6.3mm_D2.5mm | 21 | 220 |
| R83 | Resistor L6.3mm_D2.5mm | 1 | 10 |
| RV21, RV1, RV2, RV3, RV4, RV5, RV6, RV7, RV8, RV9, RV10, RV11, RV12, RV13, RV14, RV15, RV16, RV17, RV18, RV19, RV20 | Trim pot | 21 | 1k |
| S1, S2, S3, S4, S5, S6, S7, S8, S9, S10, S11, S12, S13, S14, S15, S16, S17, S18, S19, S20 | 6x6x6 (6mm tall) | 20 | 6x6x6 tactile |
| S21 | Slide switch | 1 | SS12D02 |
| U1, U2, U3, U4, U5, U6, U7, U8, U9, U10, U11, U12, U13, U14, U15, U16, U17, U18, U19, U20 | DIP-8_W7.62mm | 20 | 555 |
| U21 | TO-220F-3 Horizontal_TabDown | 1 | L7805 |
| U22 | DIP-8_W7.62mm | 1 | LM386 |

_\* 21 LEDs total in 3 colors: 1 for on/off indicator, 12 for natural notes, 8 for accidental_

### Other

| Name | Value | Count | Notes |
| --- | --- | ----- | --- |
| Socket | DIP-8 | 21 | For 555s and 386 |
| Plexiglass | 136mm x 92mm x 2.5mm | 1 | 2mm and 3mm also work |
| 1" screw | 4-40 1" long | 4 | |
| 1/4" screw | 4-40 1/4" long | 2 | |
| Square nut | 4-40 | 6 | |

## Parts

Almost all components on the POLY555 are [jelly bean parts](https://en.wiktionary.org/wiki/jellybean_part), except...

### 555s

Considerations:

- Low voltage options are better for battery performance.
- Voltage regulator's output should fall within supply voltage. This likely won't be a problem.
- Frequency range needs to cover the full spectrum of [notes](tuning.md).

#### Tested

| Model | Observed frequency range \* |
| --- | --- |
| [TLC555CP][tlc555] \*\* | 147.1 - 769.2 |
| [LMC555CN][lmc555] \*\* | 147.1 - 877.2 |
| [LM555CN][lm555cn] | 73.42 - 862.1 |

[tlc555]: https://www.ti.com/lit/ds/symlink/tlc555.pdf
[lmc555]: https://www.ti.com/lit/ds/symlink/lmc555.pdf
[lm555cn]: https://www.ti.com/lit/ds/symlink/lm555.pdf

_\* With default component values from [schematics](schematics.md)._

_\*\* Kits ship with one of these._

If using a different 555, breadboard the timer circuit first to determine its range, [adjusting the other components](hacking.md) if necessary to get to the desired note range. The downside to a wider frequency range is that it's harder to tune!

### Tactile switches

These are common enough. Make sure actuator height is 6mm, otherwise you'll be editing `BUTTON_HEIGHT`.

### Speaker

The speaker is a [SC700208](https://dbunlimitedco.com/images/product_images/2D-Drawings/SC700208-1.pdf), measuring 71mm x 41mm x 25mm. Its shape is some kind of standard; there are others that are nearly identical, like the S15X25VA.

Crucially, the depth of the cone and magnet diameter fit perfectly into the enclosure. The mounting screw holes are currently unused, though I may change that in future versions.

Using a speaker with different dimensions will necessitate modifying the enclosure to fit.

### Trimpots

IDK what the model is called but they look like this and are readily available in bulk on eBay:

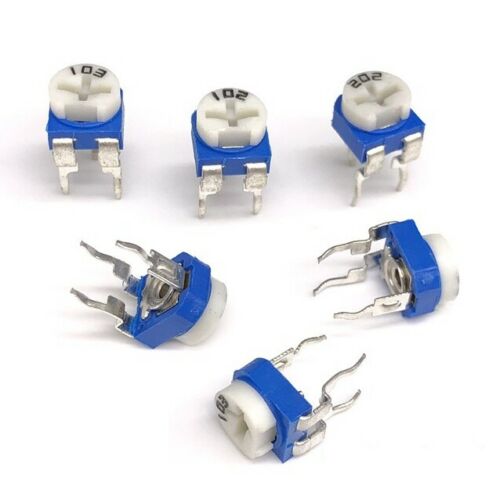
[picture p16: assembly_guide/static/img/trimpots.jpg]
Example trimpots


It is not the Bourns 3306 series.

Since it's used for both the tuners and the volume control, you may need to modify the volume wheel to fit if using a different pot.

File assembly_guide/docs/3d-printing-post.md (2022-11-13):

---
id: 3d-printing-post
title: 3D-Printing Post-Printing
sidebar_label: Post-Printing
description: How to prepare the POLY555 parts after printing
image: /img/removing_window_supports.jpg
---

:::note
If you bought the kit with the 3D-printed parts included, you can skip this part!
:::

1. Cut or pull away any stringing.
2. Carefully break or cut away built-in supports on enclosure top
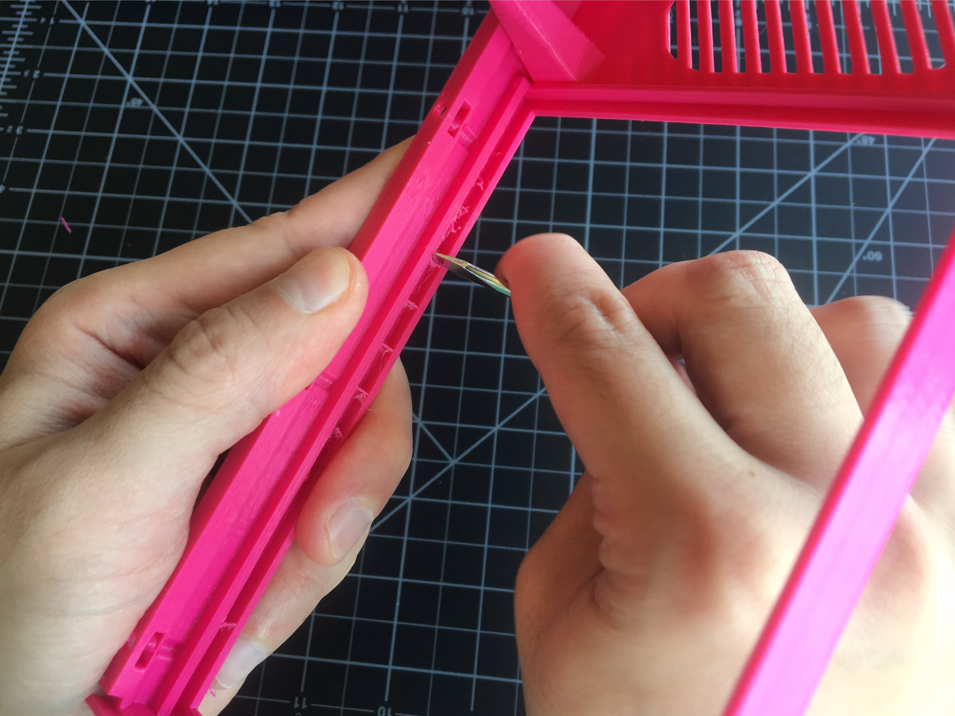
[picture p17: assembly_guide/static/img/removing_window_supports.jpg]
Removing window pane supports on enclosure top
   - Window pane supports 
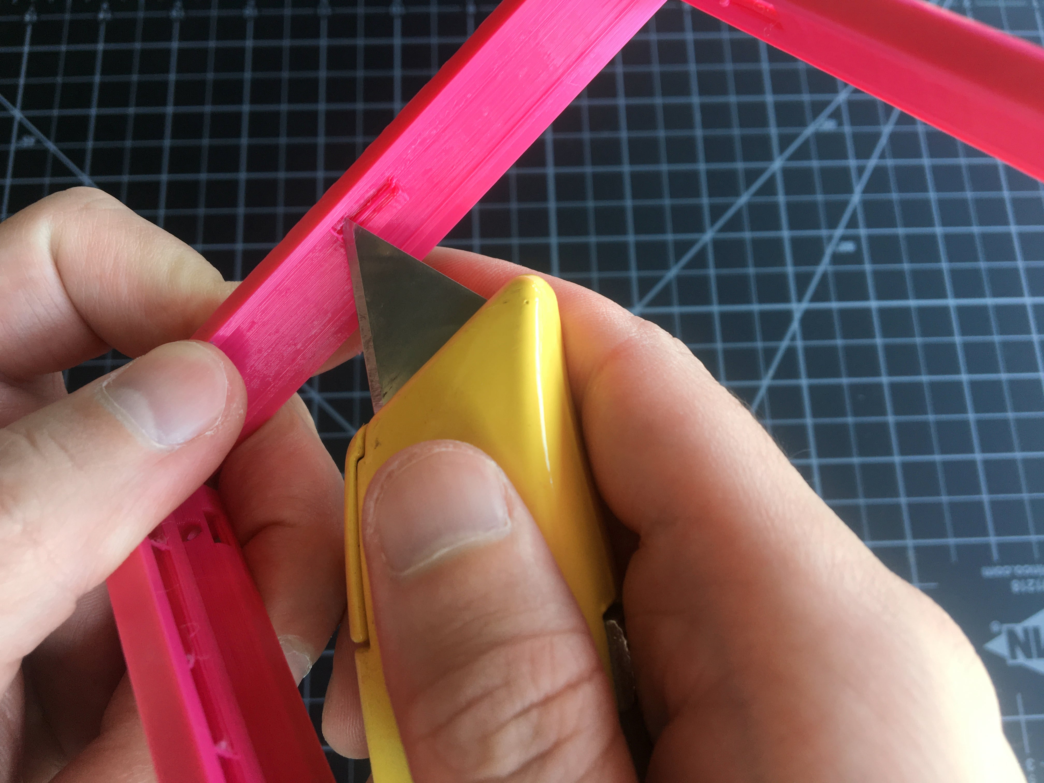
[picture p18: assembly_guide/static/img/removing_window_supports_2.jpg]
Removing window pane supports on enclosure top
   - And two that look like this 
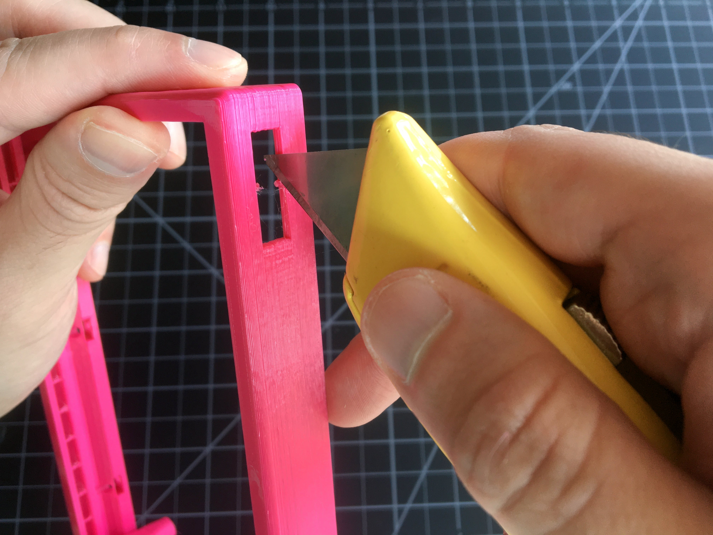
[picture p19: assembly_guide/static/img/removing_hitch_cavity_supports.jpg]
Removing supports from hitch cavities on enclosure top
   - Hitch cavities 
3. Remove supports on enclosure bottom
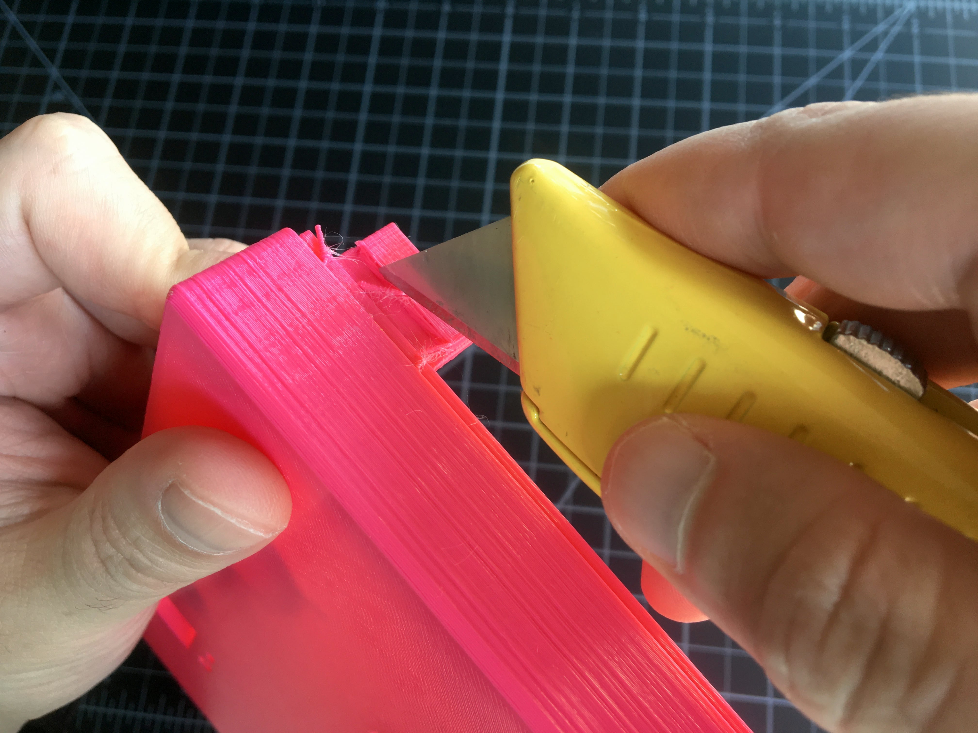
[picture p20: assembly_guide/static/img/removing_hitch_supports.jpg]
Removing supports from hitches on enclosure bottom
   - Under hitches 
4. Test fit the enclosure top and bottom together, cutting away supports until they fit together nicely without too much effort.
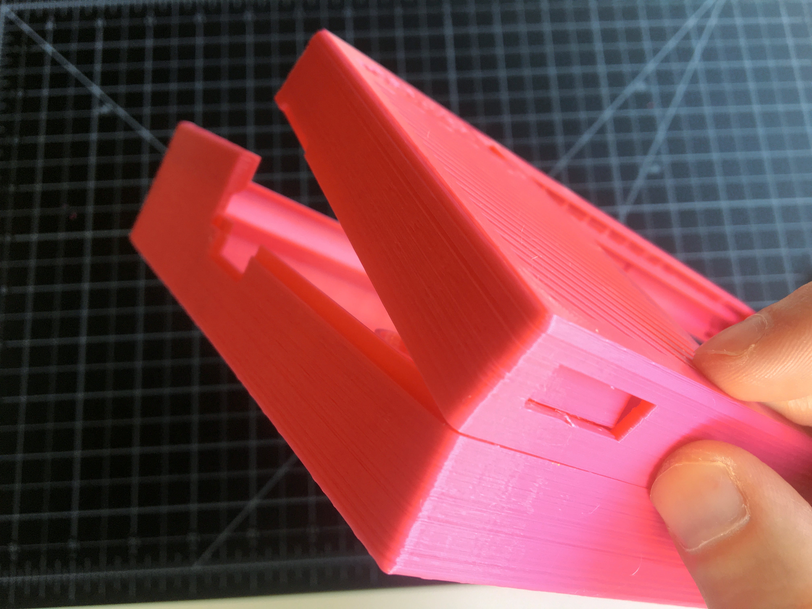
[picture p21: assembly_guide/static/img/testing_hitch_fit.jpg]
Test enclosure top and bottom fitting together


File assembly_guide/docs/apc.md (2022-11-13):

---
id: apc
title: "APC_0"
description: APC
image: /img/apc/pcb.png
---

## PCB

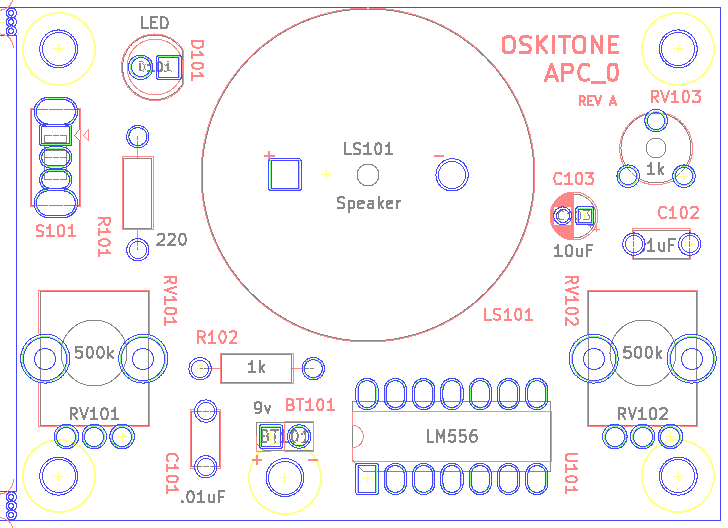
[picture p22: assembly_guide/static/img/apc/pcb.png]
pcb


## Schematic

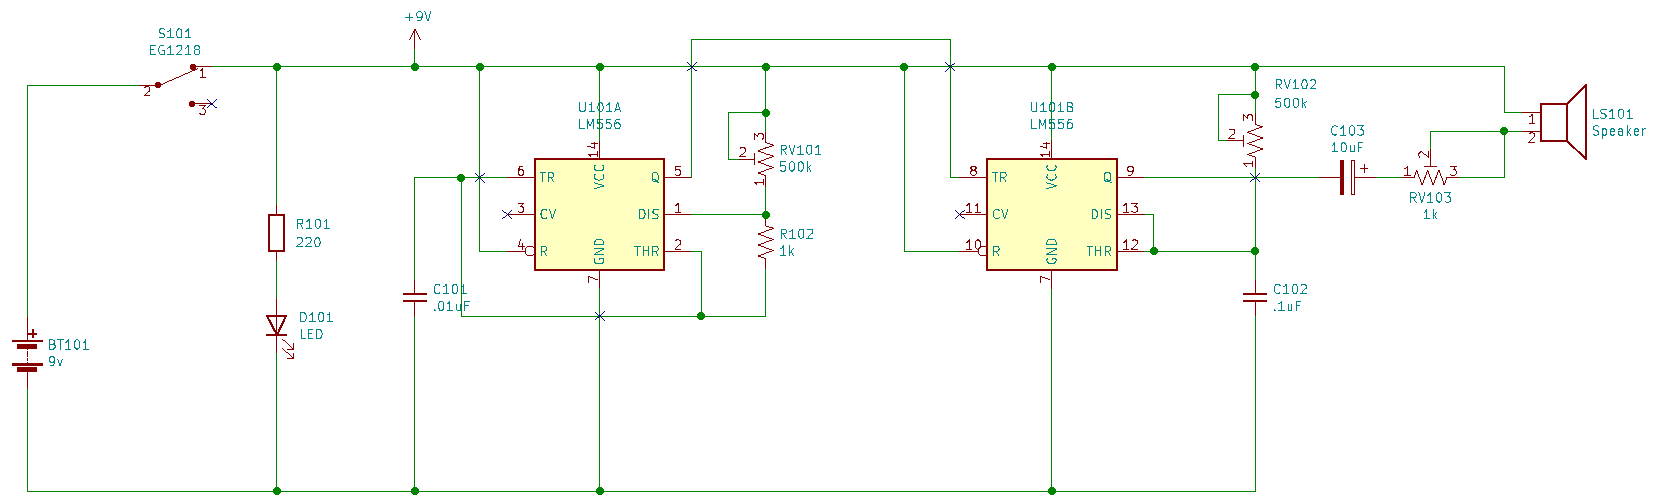
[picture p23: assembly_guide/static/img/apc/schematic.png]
schematic


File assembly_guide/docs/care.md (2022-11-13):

---
id: care
title: Care
sidebar_label: Care
description: How to care for your POLY555
image: /img/assembly/all_done.jpg
---

- Clean the plexiglass window pane with regular window cleaner.
- The trim potentiometers will hold their positions and the 555 chip is similarly resilient, but the POLY555 is an analog instrument and will lose tune over time. That's expected! [Re-tune normally](tuning.md).
- 3D-printed plastic is susceptible to warping under hot temperatures. Keep it out of prolonged direct sunlight.
- When the POLY555 seems especially out of tune, overly distorted, or doesn't turn on at all, that's a sign that its 9v battery doesn't have enough voltage. Open up the enclosure and replace it.

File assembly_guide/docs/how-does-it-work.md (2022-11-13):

---
id: how-does-it-work
title: How Does It Work?
sidebar_label: How Does It Work?
description: How does the POLY555 work?
image: /img/pcb-5-annotated.jpg
---

Inside the enclosure and under the keys is this PCB:

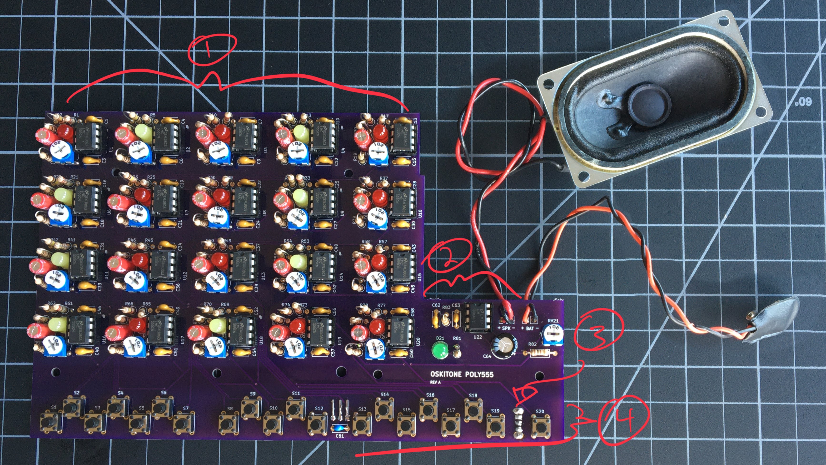
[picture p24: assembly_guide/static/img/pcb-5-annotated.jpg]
POLY555 PCB


1. **555 timers**<br />
   Twenty identical timer circuits are laid out in 4 rows of 5 columns. They'll be exposed for adoration by a plexiglass window.
2. **Amp**<br />
   A simple amplifier drives the speaker. Its volume control is exposed on the right of the enclosure.
3. **Power**<br />
   A 9v battery powers the device, which is toggled by a sliding toggle switch on the PCB's back. An LED lights up when it's on.
4. **Buttons and regulator**<br />
   Power from the switched 9v battery is regulated down to 5v by a 7805 regulator, then distributed across 20 tactile switches -- one for each timer circuit above. Regulating the voltage to a fixed 5v keeps the timers' frequencies consistent even as the battery drains.

For a deeper dive into the underlying circuit, head over to the [schematics](schematics.md).

## The keys to the keys to the timers

The switches and their timer circuits correspond numerically: S1 to U1, S2 to U2, etc.

All the timer circuits are internally identical, so, for example, the resistors are always in the same places -- once you know how where they go in one circuit, you know how to do all of them.

The circuits for the accidental keys (F#, G#, A#, C#, D#) are marked with a <code>#</code> beside their IC socket.

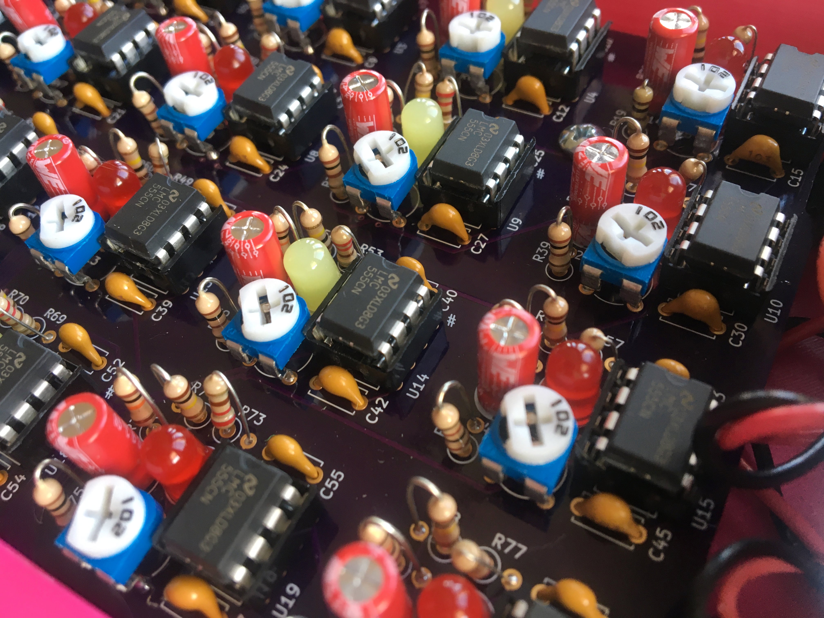
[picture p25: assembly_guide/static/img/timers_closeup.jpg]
A glamorous closeup of the 555 circuits, with accidentals marked with # sign


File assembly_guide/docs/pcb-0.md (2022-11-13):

---
id: pcb-0
title: PCB General Tips
sidebar_label: General Tips
description: General electronics assembly tips for the POLY555.
image: /img/pcb-5.jpg
---

:::caution
These general tips will apply to all PCB assembly steps, so read them and follow them carefully!
:::

## General Tips

- **IC chips are static-sensitive**<br/>
  The included IC chips can be damaged by static electricity. Leave them in their packaging until ready to install. Before handling, discharge any static electricity on your body by touching a large piece of metal. You can even use an anti-static mat and/or wrist strap for extra caution.
- **Ceramic and electrolytic capacitors**<br/>
  There are two kinds of “caps” used in this kit. Ceramic capacitors are small, circular, and have no polarity; they can be placed in either direction. Electrolytic caps are bigger, cylindrical, and have marked +/- polarities.
- **Vertical resistors**<br/>
  To save space, most resistors stand vertically instead of lay flat on the PCB.
- **ICs in sockets**<br/>
  Each IC chip comes with a corresponding socket with the same number of pins. You will solder the socket to the PCB, not the chip itself. This prevents overheating the IC with the soldering iron and makes it easier to switch a faulty one out.
- **Component polarities**<br/>
  LEDs, batteries, and electrolytic capacitors have positive and negative leads. Where applicable, the PCB will be labeled where each lead goes or a component outline to denote orientation.
- **IC orientation**<br />
  The IC chips also have an orientation, marked by a notch at their top. Make sure these line up when soldering the sockets and again when inserting the chips. A chip can be permanently damaged if inserted incorrectly!
- **Not all components go on the front**<br />
  Take a look at the back side of the PCB and note that there are outlines for two components: U21 (the 7805 voltage regulator) and S21 (the power switch). Unlike all the others, these two will mount on the back.
- **Wire relief holes**<br />
  The wires for the speaker (SPK) and battery (BAT) first go through corresponding holes before being soldered. These are meant to reduce strain on the wires as you work on the PCB.

## Component Legend

### Component Prefixes

| Prefix | Type |
| --- | --- |
| **C\***  | Capacitor (both electrolytic and cermaic) |
| **D\***  | LED |
| **R\***  | Resistor |
| **RV\*** | Resistor Variable (trimpot) |
| **S\***  | Switch |
| **U\***  | IC socket and chip |

### Resistors

export const C = ({children: color}) => (
<span style={{
    margin: '0 1rem 0 0',
    borderRadius: '4px',
  }}>
<span style={{
      backgroundColor: color,
      border: '1px solid grey',
      borderRadius: '4px',
      display: 'inline-block',
      width: '1.5rem',
      height: '1rem',
      margin: '0 .25rem 0 0'
    }} />
{color}
</span>
);

| Value | Count | Color&nbsp;Code |
| ----- | ----- | --- |
| 10 | 1 | <C>Brown</C> <C>Black</C> <C>Black</C>  |
| 100 | 21 | <C>Brown</C> <C>Black</C> <C>Brown</C>  |
| 220 | 21 | <C>Red</C> <C>Red</C> <C>Brown</C> |
| 10k | 20 | <C>Brown</C> <C>Black</C> <C>Orange</C> |
| 100k  | 20 | <C>Brown</C> <C>Black</C> <C>Yellow</C> |

### Capacitors

| Value | Count | Type | Marking |
| --- | ----- | --- | --- |
| 10nF _(or .01uF)_  | 20 | ceramic | 103 |
| 47nF _(or .046uF)_ | 1 | ceramic | 473 |
| .1uF | 21 | ceramic | 104 |
| .22uF | 1 | ceramic | 224 |
| 4.7uF | 20 | electrolytic | _n/a_ |
| 220uF | 1 | electrolytic | _n/a_ |

### LEDs

You'll have 21 LEDs total in your kit in 3 different colors:

- **1** for the **power indicator**
- **12** for the **natural keys**
- **8** for the **accidental keys**

:::note
The exact colors for each may vary across kits, which is why they're not denoted here.
:::

When you're soldering the LEDs, make sure to follow the instructions to use the right one for the job.

---

## Order of Operations

There's nothing worse than working super hard on something for hours until, when you think you've finally got it all finished and ready, you try to turn it on and find out it doesn't work...

To try to prevent that frustration, we're going to put this together incrementally. At each step, we'll solder up the fewest parts possible to verify it's working as expected before moving on to the next step.

<!-- TODO: any rewrites here? propagate out -->
<!-- TODO: maybe rename to "parts" or "chapter"? -->

1. **On and Off:**<br/>
   Get power to the board and switch the main LED on and off
2. **Timer LED Power:**<br/>
   Get power to one of the timer circuits and light its LED
3. **Make Some Noise:**<br/>
   Finish the timer circuit, add the amp circuit, and test the speaker
4. **Light All Lights:**<br/>
   Solder all the buttons and LEDs
5. **And All the Rest:**<br/>
   Finish timer circuits

This order should hopefully give you a better understanding of how it all works too!

### It will look like this before you start

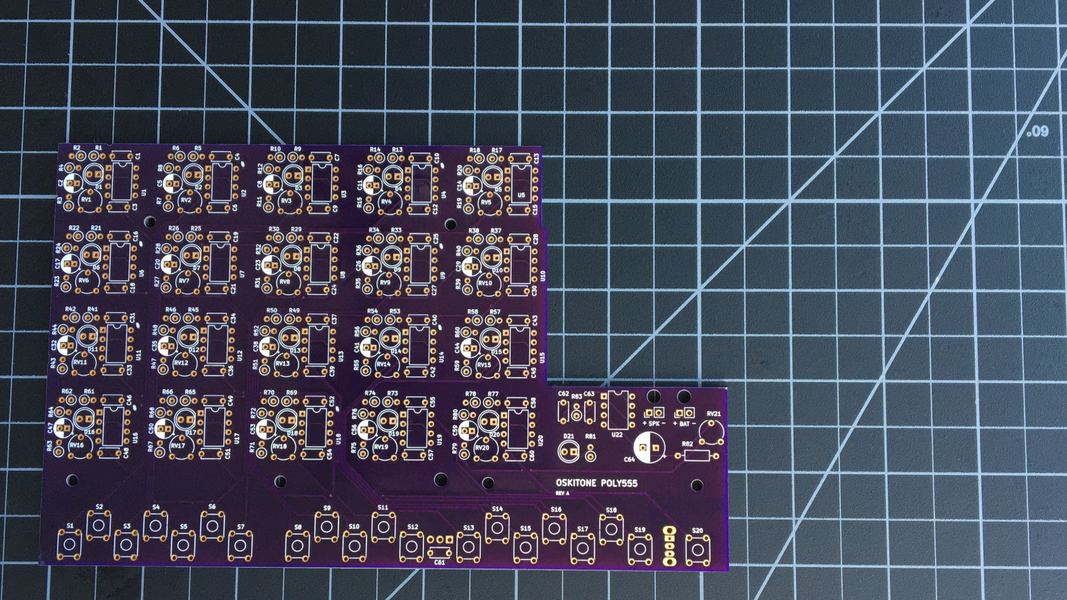
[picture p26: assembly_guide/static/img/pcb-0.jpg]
It will look like this before you start


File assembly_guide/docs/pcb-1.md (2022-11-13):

---
id: pcb-1
title: "PCB Step 1: On and Off"
description: Get power to the POLY555's board and switch the main LED on and off.
sidebar_label: "Step 1: On and Off"
image: /img/pcb-5.jpg
---

## Goal

Get power to the board and switch the main LED on and off.

## Components

- Sliding toggle switch \* 1
- 9v battery snap \* 1
- 220 resistor \* 1
- Power indicator LED \* 1

## Steps

:::tip
Double check to make sure you've got the [correct LED color](pcb-0.md#leds) before soldering!
:::

:::tip
The **S21** switch goes on the _back_ of the PCB, not the front.
:::

1. Solder the **sliding toggle switch** to **S21** on the _back_ of the PCB. There's no polarity to this component, so either way is fine as long as it's on the back side.
2. Feed the **battery snap**'s wires through the relief hole above **BAT**, then solder its wires into place: red for + and black for -.
3. Solder a **220 resistor** to **R81**.
4. Solder the **LED** to **D21**, making sure to match its outline.

### It should look something like this when done

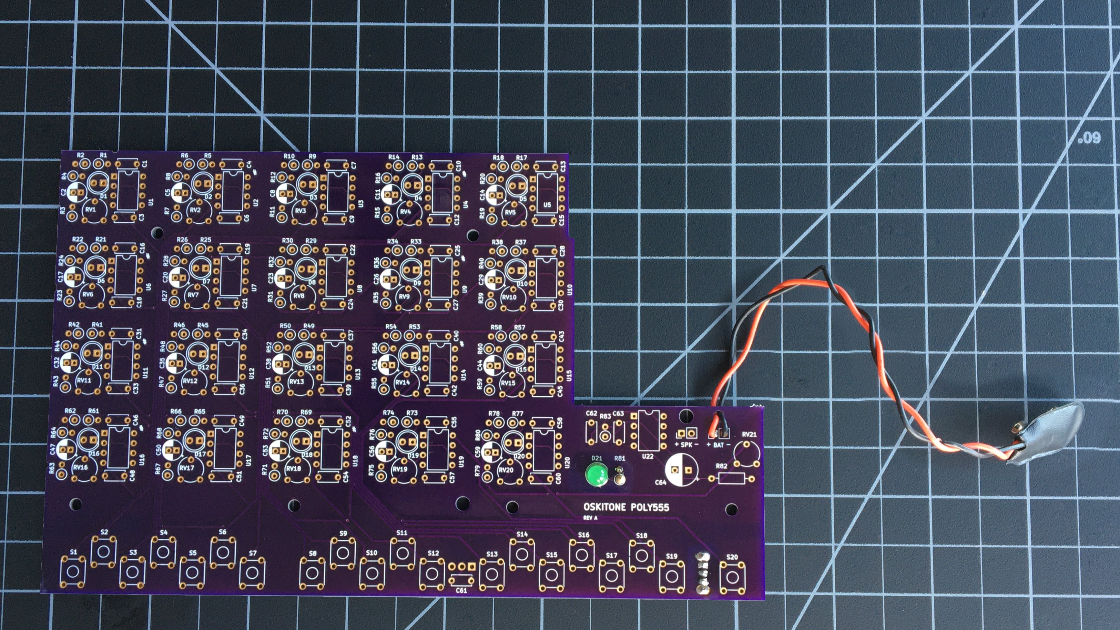
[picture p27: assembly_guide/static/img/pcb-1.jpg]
It should look something like this when done


:::note remember
The components' brands and colors for PCB, [LEDs](pcb-0.md#leds), and wires may look different from yours, and that's okay! What's important is that the part types and values are in the right spots.
:::

## Test it

Connect your battery and slide the switch back and forth. You should see the LED turn on and off!

If you have the enclosure bottom handy, you can also try inserting the PCB into it. The switch should fit nicely into its cavity and be exposed on the other side, and the screw holes should align with their counterparts.

### Troubleshooting

- [Do all the usual debugging steps like checking solder joints, etc.](debugging.md)
- Use a multimeter to confirm power is getting from battery to switch to R81 to LED
- If power is getting to LED but it isn't lighting, it may be dead. Try a different one.

## How does it work?

1. The **battery snap** connects the 9v battery to the PCB. Its negative wire (ground) goes throughout the board, but its positive wire only goes to the **sliding toggle switch** at **S21**.
2. When the **sliding toggle switch** is on, power goes from the battery to the rest of the circuit. When it's switched off, no power is used. _**S21** acts like manually connecting and disconnecting the battery._
3. The first part of the circuit to use the battery's power is the **LED** at **D21**, but first it goes through the **220 resistor** to **R81**. This is called a current-limiting resistor. Without it, the LED would burn out!

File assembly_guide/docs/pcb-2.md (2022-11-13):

---
id: pcb-2
title: "PCB Step 2: Timer LED Power"
description: Get power to one of the POLY555's timer circuits and light its LED.
sidebar_label: "Step 2: Timer LED Power"
image: /img/pcb-5.jpg
---

## Goal

Get power to one of the timer circuits and light its LED

## Components

- .22uF ceramic capacitor \* 1
- 7805 voltage regulator \* 1
- Tactile switch \* 1
- 1/4" screw \* 1
- Nut \* 1
- 220 resistor \* 1
- Natural key LED \* 1

## Steps

:::tip
Double check to make sure you've got the [correct LED color](pcb-0.md#leds) before soldering!
:::

1. Solder the **.22uF ceramic capacitor** to **C61**.
2. Solder the **7805 voltage regulator** to **U21**. <!--TODO: pictures for these would be great! -->
   1. It will _lay flat against its outline_ on the back of the PCB, with its text facing outwards, its tab pressed firmly against the exposed copper rectangle on ther PCB, and its legs bent into their holes. To help hold it there while soldering, attach its tab to the PCB with the **screw and nut**. _It's important that there's no visible gap between 7805's tab and the copper plate on the PCB_.
   2. Solder its legs on the front of the PCB.
   3. Solder its tab to the copper plate on the back of the PCB by applying solder to the sides of the tab where it meets the copper plate. You may need to use a higher temperature on your soldering iron and/or apply additional flux if using a non-flux solder.
   4. Remove the screw and nut for later use.
3. Solder a **tactile switch** into **S1**, making sure it's perfectly flat against the PCB.
   - A trick I like to do is to solder just one of its legs to hold it in place, then remelt the solder while pushing it in from the other side.
4. Solder a **220 resistor** to **R1**.
5. Solder the **LED** to **D1**, making sure to match its outline.

### It should look something like this when done

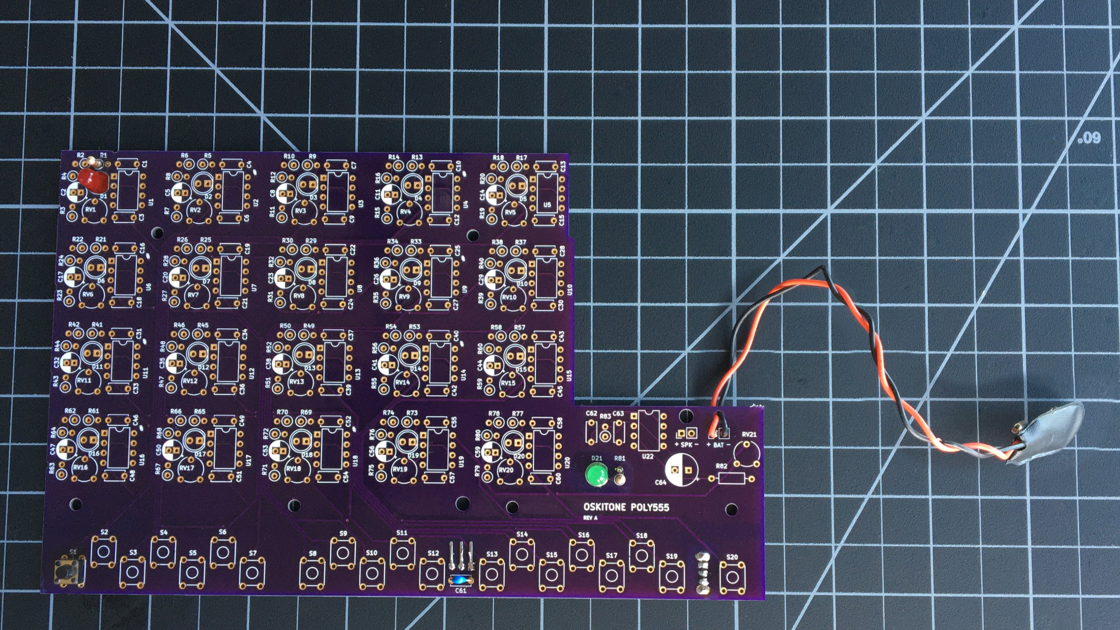
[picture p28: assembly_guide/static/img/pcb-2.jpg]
It should look something like this when done


:::note remember
The components' brands and colors for PCB, [LEDs](pcb-0.md#leds), and wires may look different from yours, and that's okay! What's important is that the part types and values are in the right spots.
:::

## Test it

With the battery attached and power switch on, press S1. You should see the LED at D1 turn on!

### Troubleshooting

- [Do all the usual debugging steps like checking solder joints, etc.](debugging.md)
- Use a multimeter to confirm 7805 has 9v going in and 5v coming out, then confirm that's going from the button to R1 when pressed.

## How does it work?

1. The **7805 voltage regulator** at **U21** takes 9v from the battery and brings it down to 5v.
   - Why would we want to do this? The 555 timers we'll solder next are sensitive to changes in voltage, and our 9v battery will slowly supply less juice as the POLY555 is used. The **7805** regulates that dwindling voltage so it's a consistent 5v. Without the regulator, the timers would quickly fall out of tune!
   - A side effect of how the **7805** works is that it creates heat &mdash; after all, that extra power has to go somewhere, right? That heat is dissipated through its tab and distributed into the "ground" of the PCB.
   - The **cap** at **C61** helps to reduce fluctuations in the output voltage.
2. When the **tactile switch** at **S1** is pressed, 5v from the regulator travels up to the first timer circuit in the board's top left corner.
3. Just like the LED from the previous step, the **LED** at **D1** has a **220 resistor** at **R1** to limit its current to a less-destructive value.

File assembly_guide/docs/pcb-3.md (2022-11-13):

---
id: pcb-3
title: "PCB Step 3: Make Some Noise"
description: Finish the POLY555's first timer circuit, add the amp circuit, and test its speaker.
sidebar_label: "Step 3: Make Some Noise"
image: /img/pcb-5.jpg
---

## Goal

Finish the timer circuit, add the amp circuit, and test the speaker.

## Components

- Timer circuit
  - 100k resistor \* 1
  - 100 resistor \* 1
  - 10k resistor \* 1
  - .1uF ceramic capacitor \* 1
  - 4.7uF electrolytic capacitor \* 1
  - 10nF ceramic capacitor \* 1
  - 1k trimmer potentiometer \* 1
  - IC socket \* 1
  - 555 timer chip \* 1
- Amp circuit
  - .1uF ceramic capacitor \* 1
  - 47nF ceramic capacitor \* 1
  - 10 resistor \* 1
  - IC socket \* 1
  - 220uF electrolytic capacitor \* 1
  - 1k trimmer potentiometer \* 1
  - 100 resistor \* 1
  - speaker \* 1
  - 386 amp chip \* 1

## Steps

1. Finish that first timer circuit
   1. Solder the **100k resistor** to **R2**.
   2. Solder a **100 resistor** to **R3**.
   3. Solder the **10k resistor** to **R4**.
   4. Solder a **.1uF ceramic capacitor** to **C1**.
   5. Solder the **4.7uF electrolytic capacitor** to **C2**.
   6. Solder the **10nF ceramic capacitor** to **C3**.
   7. Solder a **1k trimmer potentiometer** into **RV1**.
   8. Solder an **IC socket** into **U1**.
      - The legs of the socket may be bent from shipping. Make sure they're all straight and intact when inserting into PCB and before soldering. De-soldering a damaged socket is no fun! Do this for all the IC sockets for the rest of the assembly process.
2. Solder the amp circuit
   1. Solder a **.1uF ceramic capacitor** to **C62**.
   2. Solder the **47nF ceramic capacitor** to **C63**.
   3. Solder **10 resistor** to **R83**.
   4. Solder an **IC socket** into **U22**.
   5. Solder the **220uF electrolytic capacitor** to **C64**
   6. Solder a **1k trimmer potentiometer** into **RV21**.
   7. Solder a **100 resistor** to **R82**.
   8. Solder the **speaker**.
      1. Strip about 1/8" of the insulation off wire's ends.
      2. If necessary, solder wires to speaker. The lighter wire goes to + and the darker wire goes to -.
      3. Just like you did for the battery snap, feed wires through the relief hole above **SPK**, then solder them into place: lighter wire to + and darker to -.
3. Insert IC chips
   1. Insert the **555 timer chip** into its socket at **U1**, making sure it's in the right orientation: a notch or dimple at the top of the chip should match the notch in the footprint outline on the PCB.
   2. Insert the **386 amp chip** into its socket at **U22**, again making sure its in the right orientation. You'll do this for all chips throughout assembly.

### It should look something like this when done

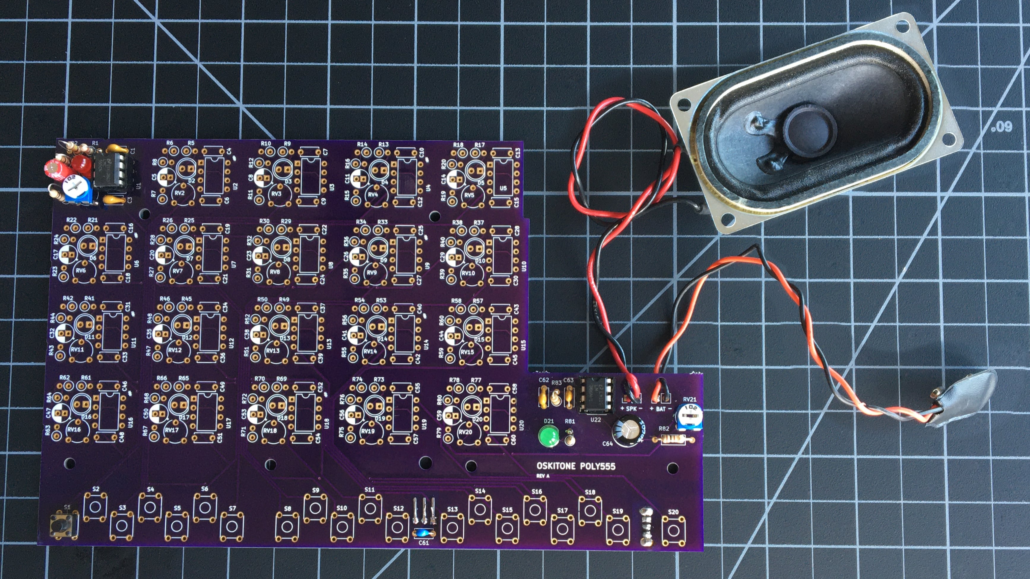
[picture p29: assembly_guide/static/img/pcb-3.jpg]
It should look something like this when done


:::note remember
The components' brands and colors for PCB, [LEDs](pcb-0.md#leds), and wires may look different from yours, and that's okay! What's important is that the part types and values are in the right spots.
:::

## Test it

1. With the **battery** attached, turn the power switch on. You should hear a little "boomp" noise from the **speaker** as it's powered by the amp.
2. Press **S1** again. In addition to the LED being lit, you should now hear an audible tone out of the speaker!
3. Try adjusting the pot at **RV1**. Turning it clockwise should make the frequency go up, and vice-versa.
4. Try the same on the volume pot at **RV21**. Clockwise should make the sound quieter, and counter-clockwise will be louder.

### Troubleshooting

- [Do all the usual debugging steps like checking solder joints, etc.](debugging.md)
- Check to see that the volume potentiometer at **RV21** isn't turned all the way down.

## How does it work?

1. First, the **555 timer** circuit
   1. The **.1uF ceramic capacitor** at **C1** is what's called a "bypass cap" and reduces voltage fluctuations as the chip pulls in power.
   2. The frequency of the timer is set by the **4.7uF electrolytic capacitor** at **C2**, the **100k resistor** at **R2**, the **100 resistor** at **R3**, and the **1k trimmer potentiometer** (aka "variable resistor") at **RV1**. **R3** and **RV1** are connected serially and their values sum together &mdash; the range of available resistances is, roughly, 100 to 1100.
   3. The **10nF ceramic capacitor** at **C3** ties the 555's "control voltage" pin to ground. You may see other 555 oscillator circuits that use an analog voltage on this pin to control its frequency, but, since ours is tuned with the pot at **RV1**, we just bring it down to ground, which will always be 0v.
   4. When the switch at **S1** is pressed, power is supplied to its LED and this 555 chip. A square wave outputs from its pin 3 and goes through the **10k resistor** at **R4** before heading off to the amp circuit. This resistor is a "mixer" and prevents the other timers' outputs from interfering with each other.
2. Next, the **386** amp
   1. The timers' output mixing resistors all connect at one of the pins of our volume pot, the **1k trimmer potentiometer** at **RV21**, which is wired as a voltage divider. Depending on where the pot is set, a certain amount of sound is either dumped to ground or sent off to be amplified.
   2. The **100 resistor** at **R82** connects across two of the pins of the volume pot and changes the sweep of the pot from linear to something closer to logarithmic, which is what our ears expect to hear. <!-- TODO: explain better! -->
   3. The **.1uF ceramic capacitor** at **C62** is another bypass cap and helps to prevent static noise from the amp.
   4. The **10 resistor** at **R83** and **47nF ceramic capacitor** at **C63** act as a "snubber" to suppress the amp from triggering itself into oscillation.
   5. Output from the amp goes through the **220uF electrolytic capacitor** at **C64** before connecting to the **speaker**.

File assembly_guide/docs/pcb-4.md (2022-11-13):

---
id: pcb-4
title: "PCB Step 4: Light All Lights"
description: Solder all the buttons and LEDs on the POLY555.
sidebar_label: "Step 4: Light All Lights"
image: /img/pcb-5.jpg
---

## Goal

Solder all the buttons and LEDs.

## Components

- Tactile switch \* 19
- 220 resistor \* 19
- Natural key LED \* 11
- Accidental key LED \* 8

## Steps

:::tip
Double check to make sure you've got the [correct LED colors](pcb-0.md#leds) before soldering!
:::

1. Solder the 19 **tactile switches** into **S2**, **S3**, **S4**, **S5**, **S6**, **S7**, **S8**, **S9**, **S10**, **S11**, **S12**, **S13**, **S14**, **S15**, **S16**, **S17**, **S18**, **S19**, and **S20**. Make sure they're perfectly flat against the PCB, just like **S1**!
2. Solder 19 **220 resistors** to **R5**, **R9**, **R13**, **R17**, **R21**, **R25**, **R29**, **R33**, **R37**, **R41**, **R45**, **R49**, **R53**, **R57**, **R61**, **R65**, **R69**, **R73**, and **R77**.
3. Solder the remaining 11 **LEDs for the natural keys** to **D3**, **D5**, **D7**, **D8**, **D10**, **D12**, **D13**, **D15**, **D17**, **D19**, **D20**.
4. Solder the 8 **LEDs for the accidental keys** to **D2**, **D4**, **D6**, **D9**, **D11**, **D14**, **D16**, and **D18**.

### It should look something like this when done

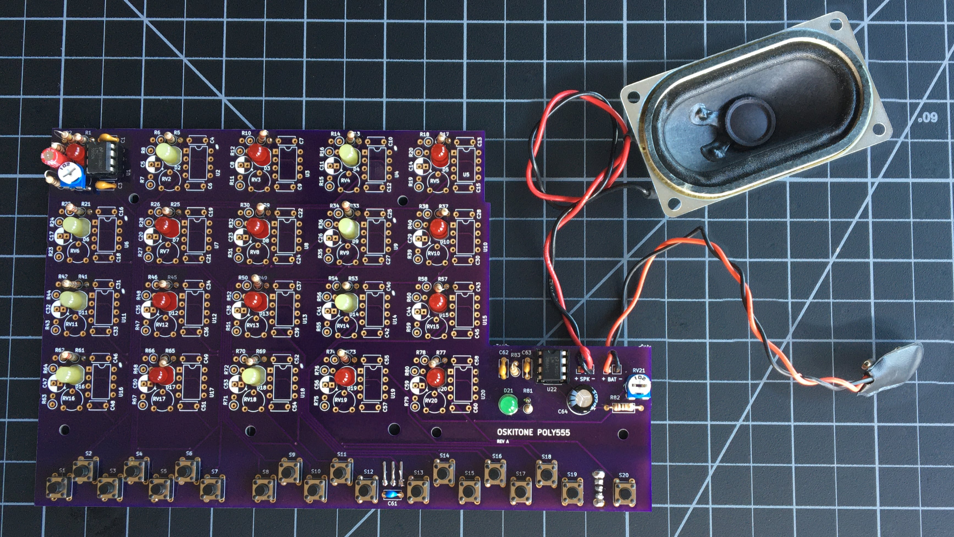
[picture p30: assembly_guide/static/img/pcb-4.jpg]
It should look something like this when done


:::note remember
The components' brands and colors for PCB, [LEDs](pcb-0.md#leds), and wires may look different from yours, and that's okay! What's important is that the part types and values are in the right spots.
:::

## Test it

With the battery attached and power switch on, press buttons **S2** through **S20**. You should see each of its corresponding LEDs light up, just like **S1**!

### Troubleshooting

- [Do all the usual debugging steps like checking solder joints, etc.](debugging.md)
- Do the same troubleshooting checks you did in [Step 2: Timer LED Power](pcb-2.md#troubleshooting) for all the buttons and LEDs.

## How does it work?

1. When any **tactile switch** is pressed, 5v from the regulator travels up to its corresponding timer circuit.
2. Its **LED** lights up, with help from its current-limiting **220 resistor**.

Just like in [PCB Step 2: Timer LED Power](/pcb-2#how-does-it-work)!

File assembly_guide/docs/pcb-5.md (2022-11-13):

---
id: pcb-5
title: "PCB Step 5: And All the Rest"
description: Finish the POLY555's timer circuits.
sidebar_label: "Step 5: And All the Rest"
image: /img/pcb-5.jpg
---

## Goal

Finish timer circuits.

:::tip

You've got this! Keep going!

This step will take the longest time, but, if you've made it this far, it should be relatively straightforward... Everything you're doing here you've already done somewhere else!

:::

## Components

- Timer circuit \* 19
  - 100k resistor \* 1
  - 100 resistor \* 1
  - 10k resistor \* 1
  - .1uF ceramic capacitor \* 1
  - 4.7uF electrolytic capacitor \* 1
  - 10nF ceramic capacitor \* 1
  - 1k trimmer potentiometer \* 1
  - IC socket \* 1
  - 10 resistor \* 1
  - 555 timer chip \* 1

## Steps

Just like we did for the timer in [Step 3: Make Some Noise](pcb-3.md#steps), we'll be soldering up the remaining 19 timers.

Rather than list out all the component footprints by number, it's helpful this time to just go by location. You'll probably find that it's easiest to do them all by type; ie, solder all the resistors before moving onto caps, etc.

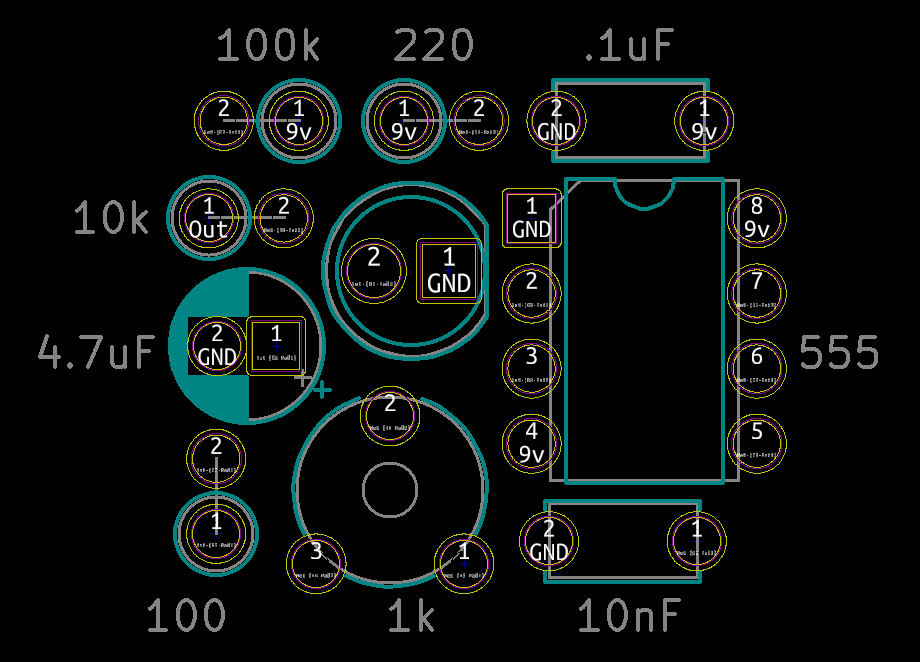
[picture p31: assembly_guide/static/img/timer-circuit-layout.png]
The PCB's 555 timer circuit, without specific component IDs, for reference


### It should look something like this when done

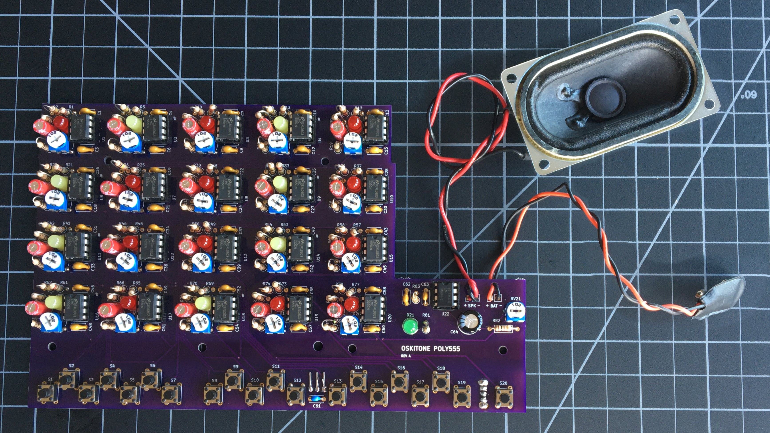
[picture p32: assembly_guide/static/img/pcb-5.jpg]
It should look something like this when done


:::note remember
The components' brands and colors for PCB, [LEDs](pcb-0.md#leds), and wires may look different from yours, and that's okay! What's important is that the part types and values are in the right spots.
:::

## Test it

With the battery attached and power switch on, press buttons **S2** through **S20**. You should now hear audible tones out of the speaker!

### Troubleshooting

- [Do all the usual debugging steps like checking solder joints, etc.](debugging.md)
- Do the same troubleshooting checks you did in [Step 3: Make Some Noise](pcb-3.md#troubleshooting) but for all the timer circuits.

If all is well, congrats! The hard parts are over. Now's a good time to go wash your hands to get rid of any soldering residue.

## How does it work?

1. When any **tactile switch** is pressed, 5v from the regulator travels up to its corresponding timer circuit, lighting its LED and powering its 555.

Just like in [PCB Step 3: Make Some Noise](/pcb-3#how-does-it-work)!

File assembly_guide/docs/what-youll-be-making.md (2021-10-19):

---
id: what-youll-be-making
title: Oskitone POLY555 Assembly Guide
sidebar_label: What You'll Be Making
description: The POLY555 is a polyphonic, analog, square wave synth based on the 555 timer chip.
image: /img/assembly/all_done.jpg
slug: /
---

A finished POLY555

**Purchase:**

- [POLY555 Synth](https://www.oskitone.com/product/poly555-synth) (fully assembled)
- [Electronics Kit](https://www.oskitone.com/product/poly555-synth-diy-kit), [3D-Printed Parts](https://www.oskitone.com/product/poly555-synth-3d-printed-parts)

## What you'll be making

The POLY555 is a _polyphonic_, analog, square wave synth based on the _555_ timer chip.

- **Polyphonic:** Multiple notes can be played simultaneously. This is opposed to "monophonic," where only one note at a time can be played.
- **Analog:** There are no computers, microcontrollers, sound samplers, or anything digital involved. The sound you hear is the sound of a speaker being abused by discrete electronic components like capacitors and resistors and logic chips.
- **Square-wave:** When its output is viewed on an oscilloscope, its wave resembles a square. It’s a “hard” sounding wave type, commonly associated with chiptune music and old video games

<p><iframe src="https://player.vimeo.com/video/487720782" width="640" height="360" frameborder="0" allow="autoplay; fullscreen" allowfullscreen></iframe></p>

More information on the POLY555, its development, and history: <br />
[https://blog.tommy.sh/posts/poly555-synth/](https://blog.tommy.sh/posts/poly555-synth/)

### Disclaimers

You've been warned!

:::warning
Not a toy. Choking hazard. Small parts. Not for children under 3 years.
:::

:::caution
Recommended for advanced users! This kit has over 250 pieces and can take 5+ hours to put together. It requires a solid grasp of electronics and through-hole soldering.
:::

## About this guide

To save cost, trees, and frustration from outdated information, printed instructions are not included by default with POLY555 kits. This online guide will always be up to date and be the best source of information for how to assembly your new POLY555.

Thank you for understanding!

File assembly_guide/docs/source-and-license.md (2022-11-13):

---
id: source-and-license
title: "Appendix: Source and License"
description: The POLY555 is open-source hardware.
sidebar_label: Source and License
image: /img/assembly/all_done.jpg
---

## Source

The POLY555 is open-source hardware.

[https://github.com/oskitone/poly555](https://github.com/oskitone/poly555)

## License

> Designed by Oskitone. Please support future synth projects by purchasing from [Oskitone](https://www.oskitone.com/).
>
> Creative Commons Attribution/Share-Alike, all text above must be included in any redistribution. See license.txt for additional details.

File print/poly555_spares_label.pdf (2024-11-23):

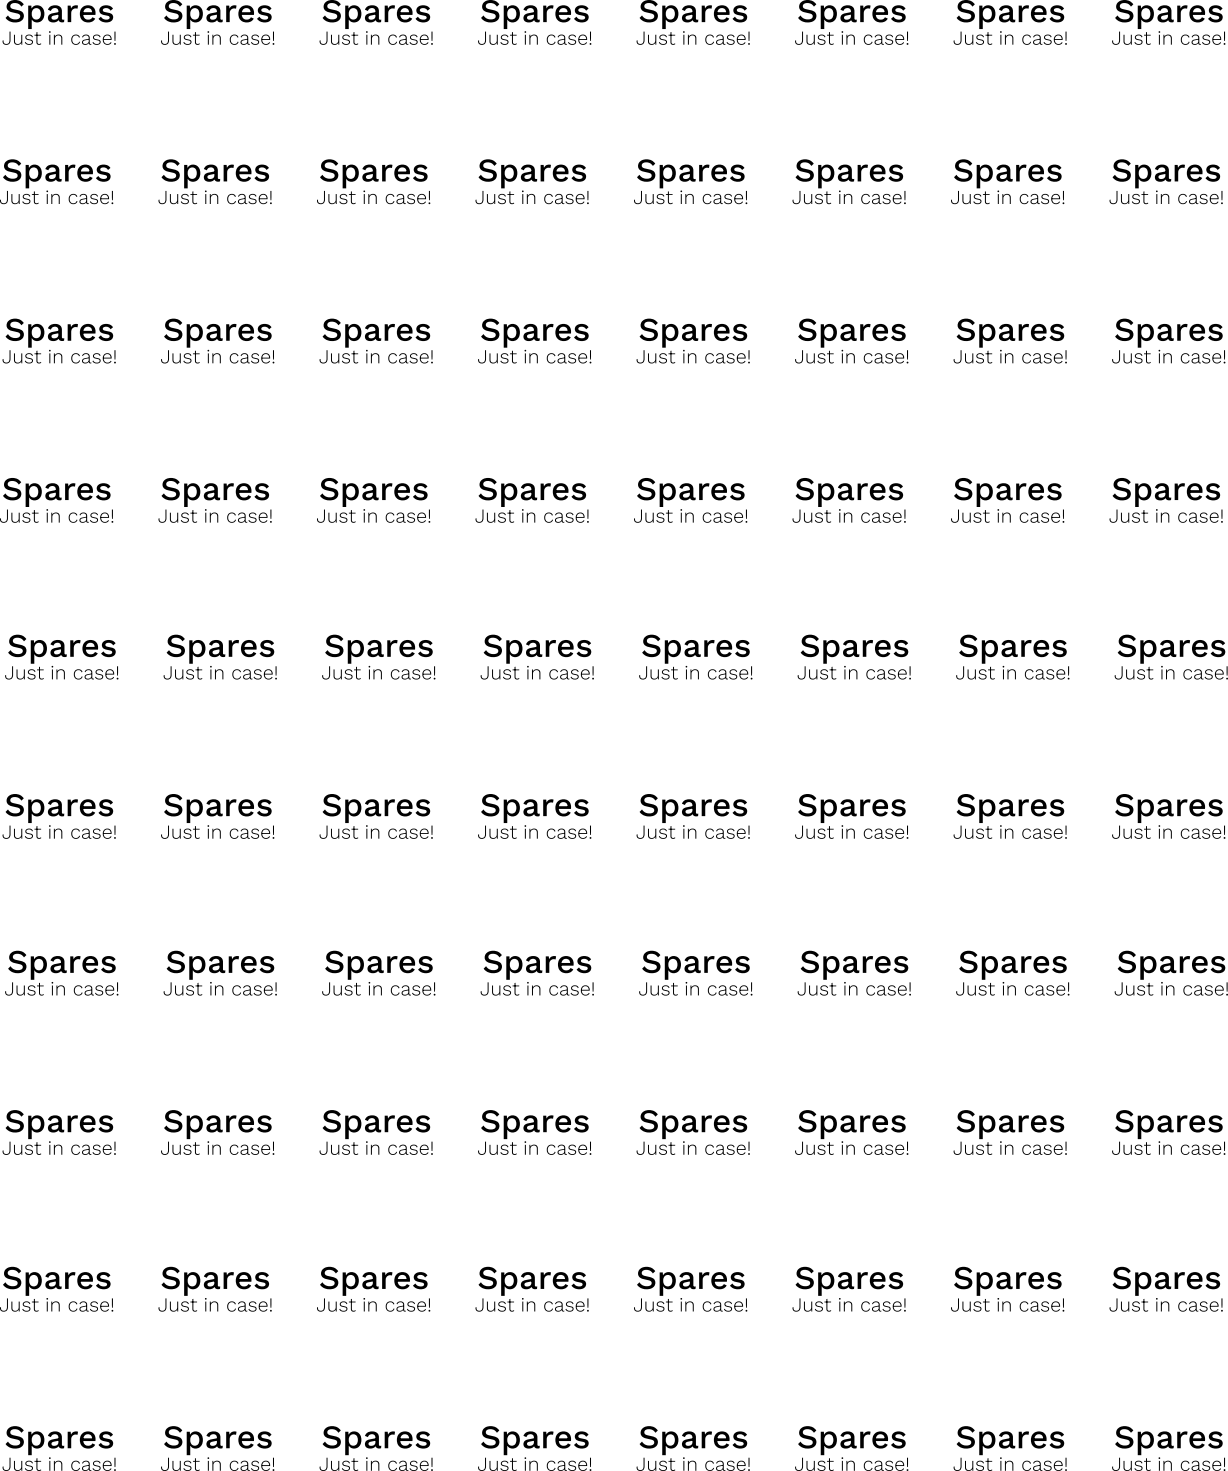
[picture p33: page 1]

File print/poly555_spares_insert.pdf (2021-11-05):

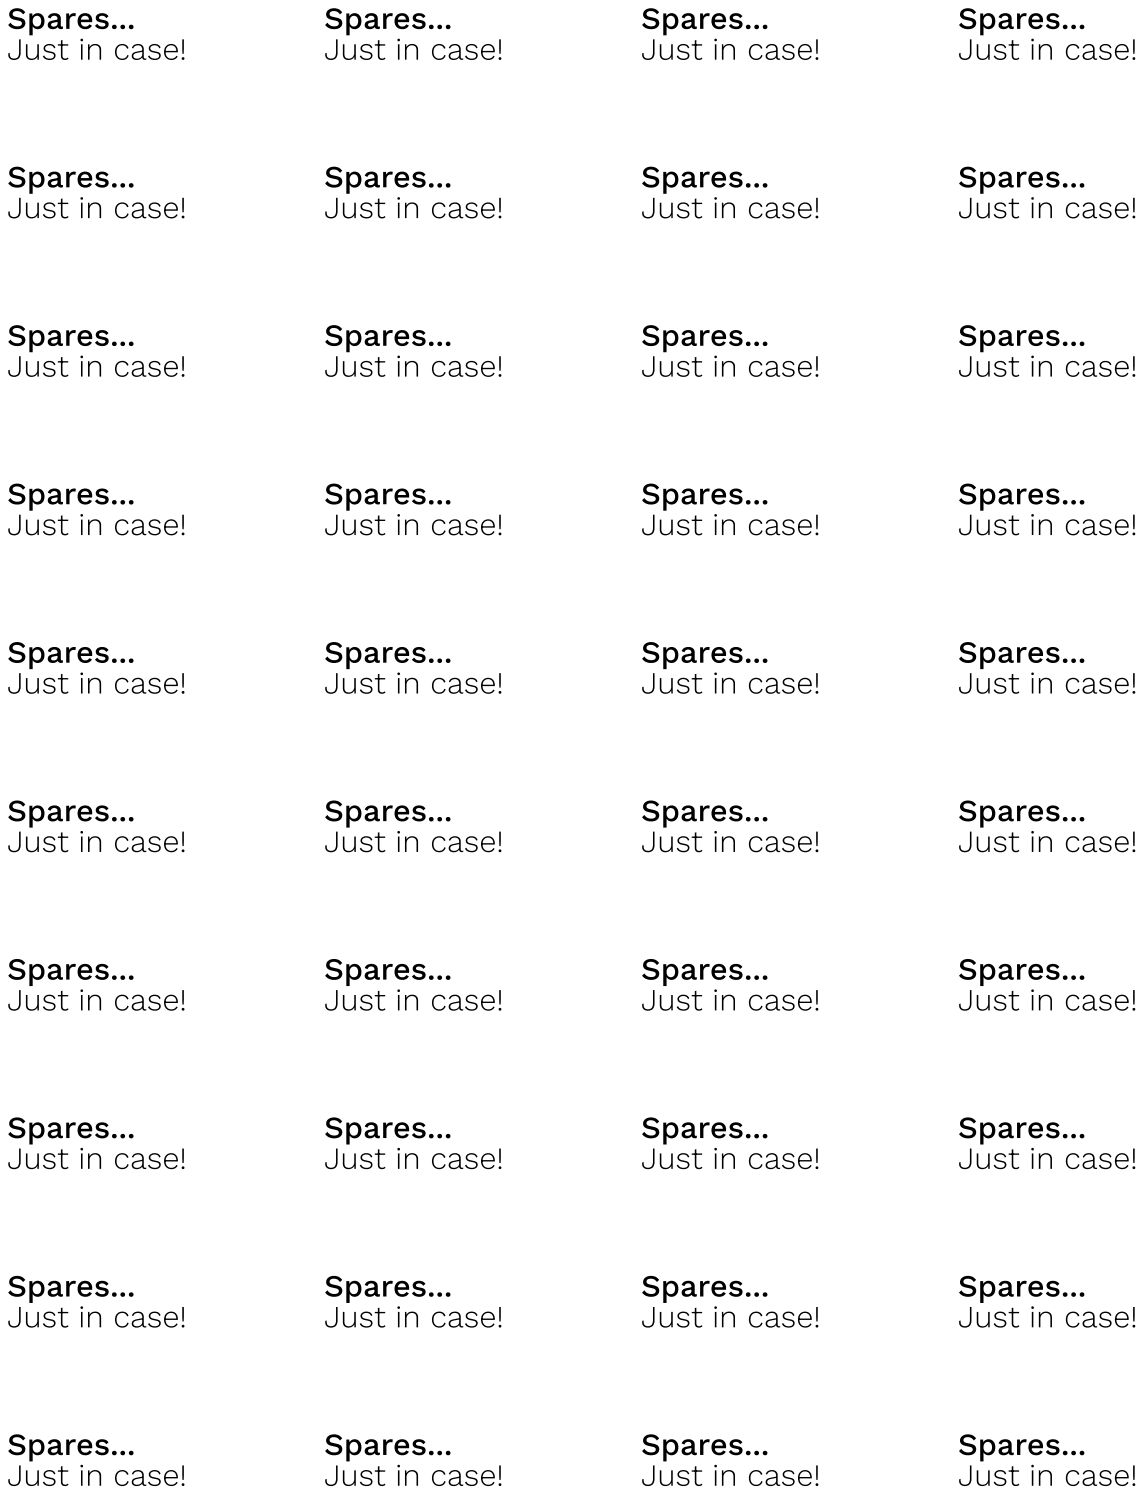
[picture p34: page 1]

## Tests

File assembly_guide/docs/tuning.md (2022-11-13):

---
id: tuning
title: Tuning
description: Tuning the POLY555.
sidebar_label: Tuning
image: /img/tuning.jpg
---

:::tip
The timer circuits are independant, so you can tune their notes in any order.
:::

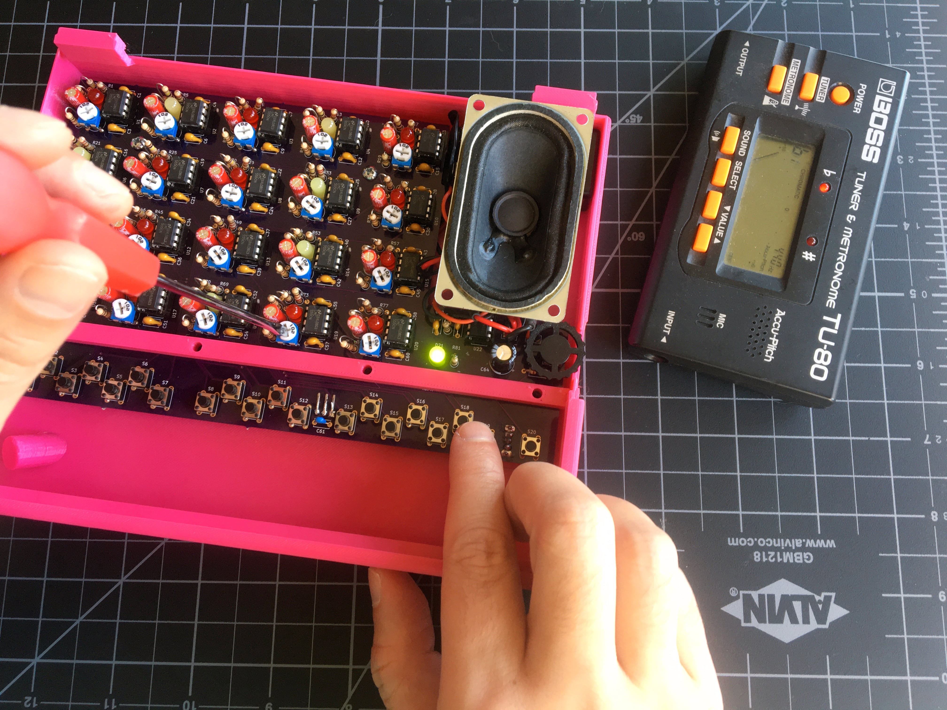
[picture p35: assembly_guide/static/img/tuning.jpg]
Tuning the POLY555


1. If it's already assembled, remove **enclosure top** and **keys**
2. Get your tuner ready and place it by the speaker. Turn the POLY555's volume up so the tuner can hear it.
3. Holding any **S\*** switch, adjust its respective **RV\*** trim pot with a small flathead screwdriver until its note is correct. See frequency table below.

## Frequency table

| Switch | Trim Pot | Note | Frequency |
| --- | --- | ---- | --- |
| S1 | RV1 | F3 | 174.61 |
| S2 | RV2 | F#3  | 185.00 |
| S3 | RV3 | G3 | 196.00 |
| S4 | RV4 | G#3  | 207.65 |
| S5 | RV5 | A3 | 220.00 |
| S6 | RV6 | A#3  | 233.08 |
| S7 | RV7 | B3 | 246.94 |
| S8 | RV8 | C4 | 261.63 |
| S9 | RV9 | C#4  | 277.18 |
| S10 | RV10 | D4 | 293.66 |
| S11 | RV11 | D#4  | 311.13 |
| S12 | RV12 | E4 | 329.63 |
| S13 | RV13 | F4 | 349.23 |
| S14 | RV14 | F#4  | 369.99 |
| S15 | RV15 | G4 | 392.00 |
| S16 | RV16 | G#4  | 415.30 |
| S17 | RV17 | A4 | 440.00 |
| S18 | RV18 | A#4  | 466.16 |
| S19 | RV19 | B4 | 493.88 |
| S20 | RV20 | C5 | 523.25 |

## Using an oscilloscope

Referring to the [schematics](schematics.md), we can see the 555s' outputs converge on RV21.

Attach your oscilloscope probe to its left leg to view the raw square waves before they get sent to the 386. Ground is RV21's right leg, on the speaker, and a bunch of other places!

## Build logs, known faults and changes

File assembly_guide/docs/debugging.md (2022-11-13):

---
id: debugging
title: "Appendix: Debugging"
sidebar_label: Debugging
description: Debugging/troubleshooting tips for assembling the POLY555
image: /img/assembly/all_done.jpg
---

Stuck? Happens to the best of us. Try these general debugging steps:

- Turn the boards over and check all solder joints. A majority of problems are caused by insufficient or errant soldering. Familiarize yourself with what a good joint looks like in the [Adafruit Guide To Excellent Soldering](https://learn.adafruit.com/adafruit-guide-excellent-soldering)
- Are all chips in the right orientation? Each has a notch/dimple that should match the footprint outline on the PCB.
- Make sure battery still has power. The 7805 voltage regulator needs at least 7v to work.
- Using a multimeter’s voltage meter, check power at the battery, the switch, the 7805, the switches, and the IC chips. Refer to the schematics to make sure the power is getting to the appropriate IC pins.
- If there’s buzzing, check for any metal scraps stuck to the speaker’s magnet.
- Like arcade console buttons, the tactile switches are mechanical and will eventually wear out over time and vigorous usage. Substitute for a new button (google “6x6x6 tactical switch”).

## Troubleshooting

- **A note is stuck on**<br />
  The key mounting screw(s) may be too tight. Try loosening until the note turns off.
- **A note turns off when pressing another near it**<br />
  The key mounting screw(s) may be too loose. Try tightening.
- **A note and its LED are acting funny**<br />
  Power isn't getting to the circuit correctly. Check its button's soldering. If the circuit responds to pushing the button down in different ways (like softly vs gently, at certain angles), rather than just on or off, the button may need replacing.
- **A note is acting funny but its LED is fine**<br />
  Since the LED lights, the timer circuit is getting power, so it must be its components. Check solder joints and components for damage. Try swapping its 555 with a known-good note.
- **The LEDs light up when pressing keys but no sounds come out**<br />
  1. Confirm the speaker itself isn't broken
     - On the POLY555, you can try skipping the amp circuit by pulling the 386 out of its socket and connecting its pin 5 (the amp's output that would normally go to the big capacitor at C64 and then the speaker) to pin 3 (the 555's output) of one of the 555s. It won't be loud (because it's not amplified anymore), but, if the speaker isn't broken, there should be a low rumble.
     - Alternatively, you can also try hooking the POLY555's speaker up to the headphone output of another small music device.
  2. Confirm the 386 and volume pot aren't broken
     - With the 386 chip back in its socket, try shorting the left two pins of the volume pot at RV21.
     - If it's LOUD when playing, that means the 386 is working but the volume pot is broken. Swap it with a spare.
     - If it's still muted but the test above confirmed the speaker works, the 386 might be fried or its circuit needs some re-solder work.
- **The high notes are too low and can't be tuned any higher**<br />
  Try changing the battery!
- **Individual notes play fine but holding down multiple keys causes a weird distortion**<br />
  Try changing the battery!

## Something else?

[Contact me](https://www.oskitone.com/contact)! The more I hear about what problems folks run into, the better I can make the assembly guide! :)

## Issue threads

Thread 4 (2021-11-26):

link broken for LED colors

montoyamoraga, 2021-11-26:
https://oskitone.github.io/poly555/pcb-1/pcb-0#leds
if i find a solution i will send a PR :)

rocktronica, 2022-01-24:
Eeek! Thanks for reporting.

Fixed in 43d4d2669502e73d5e1095df3474e6e2c91c1a7f

Closed 2022-01-24.

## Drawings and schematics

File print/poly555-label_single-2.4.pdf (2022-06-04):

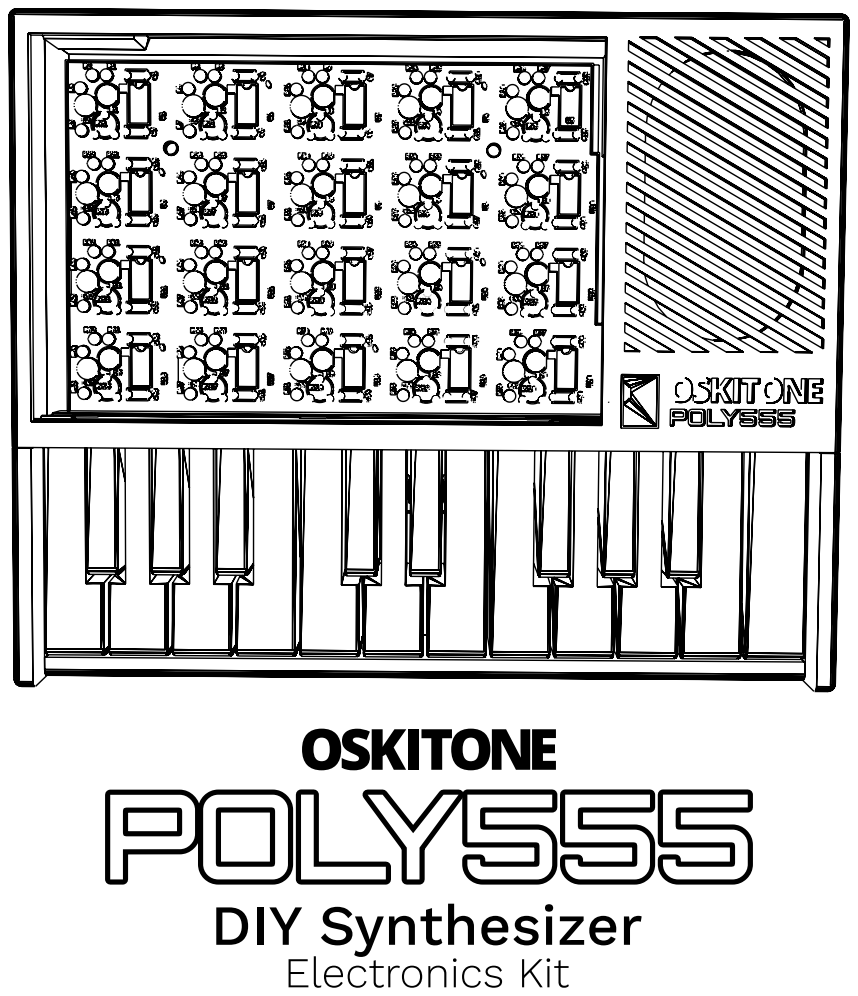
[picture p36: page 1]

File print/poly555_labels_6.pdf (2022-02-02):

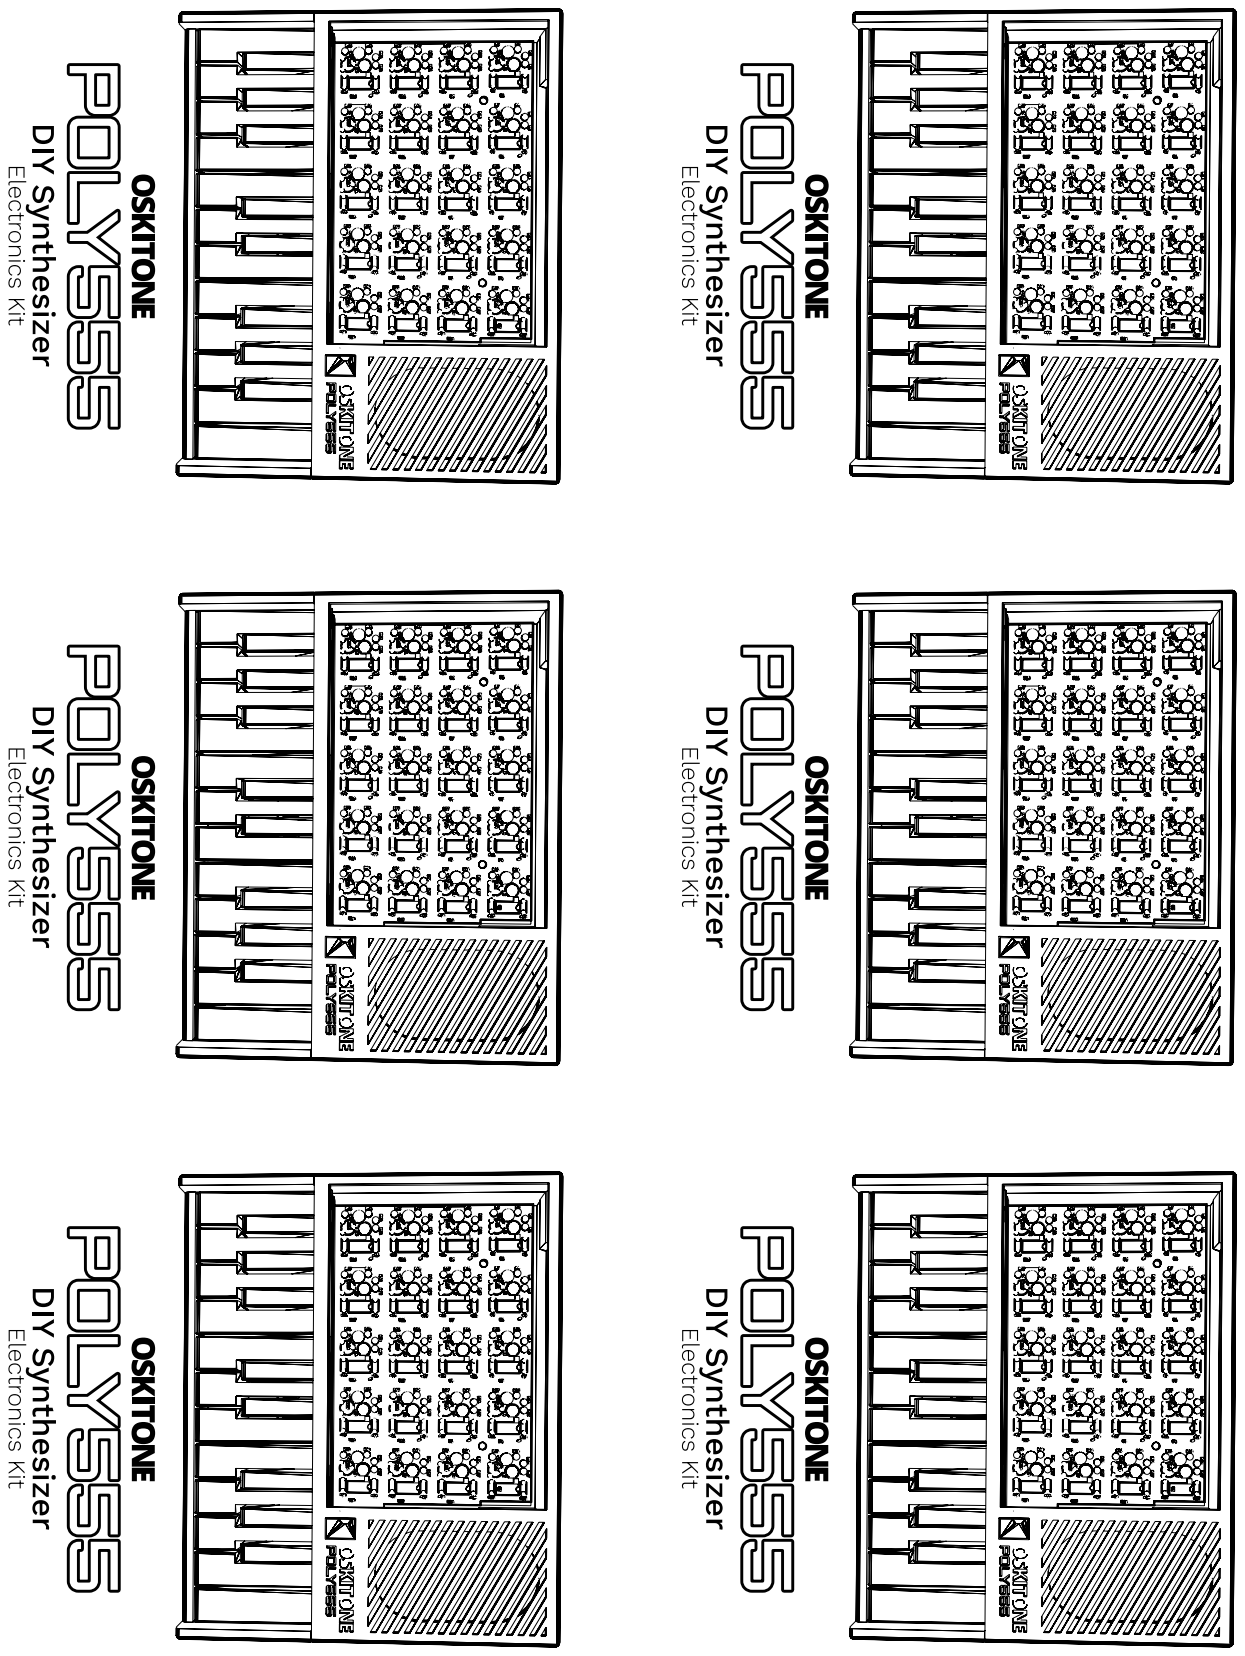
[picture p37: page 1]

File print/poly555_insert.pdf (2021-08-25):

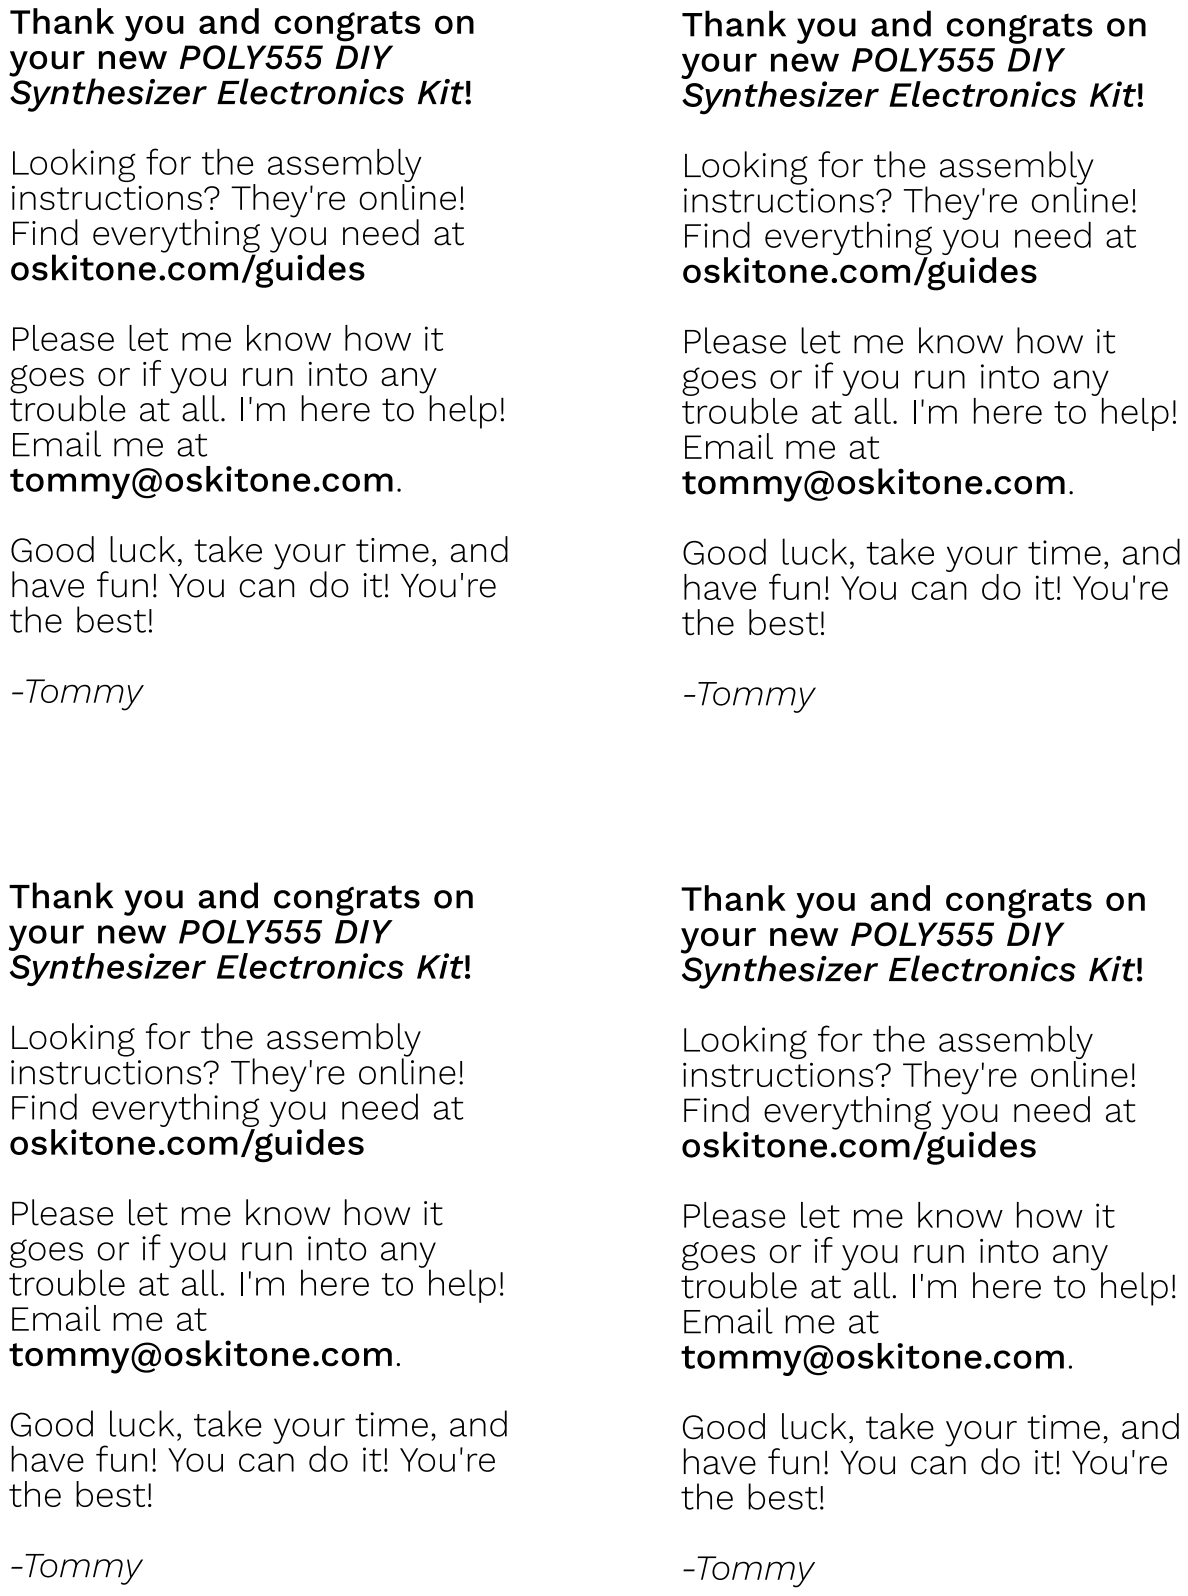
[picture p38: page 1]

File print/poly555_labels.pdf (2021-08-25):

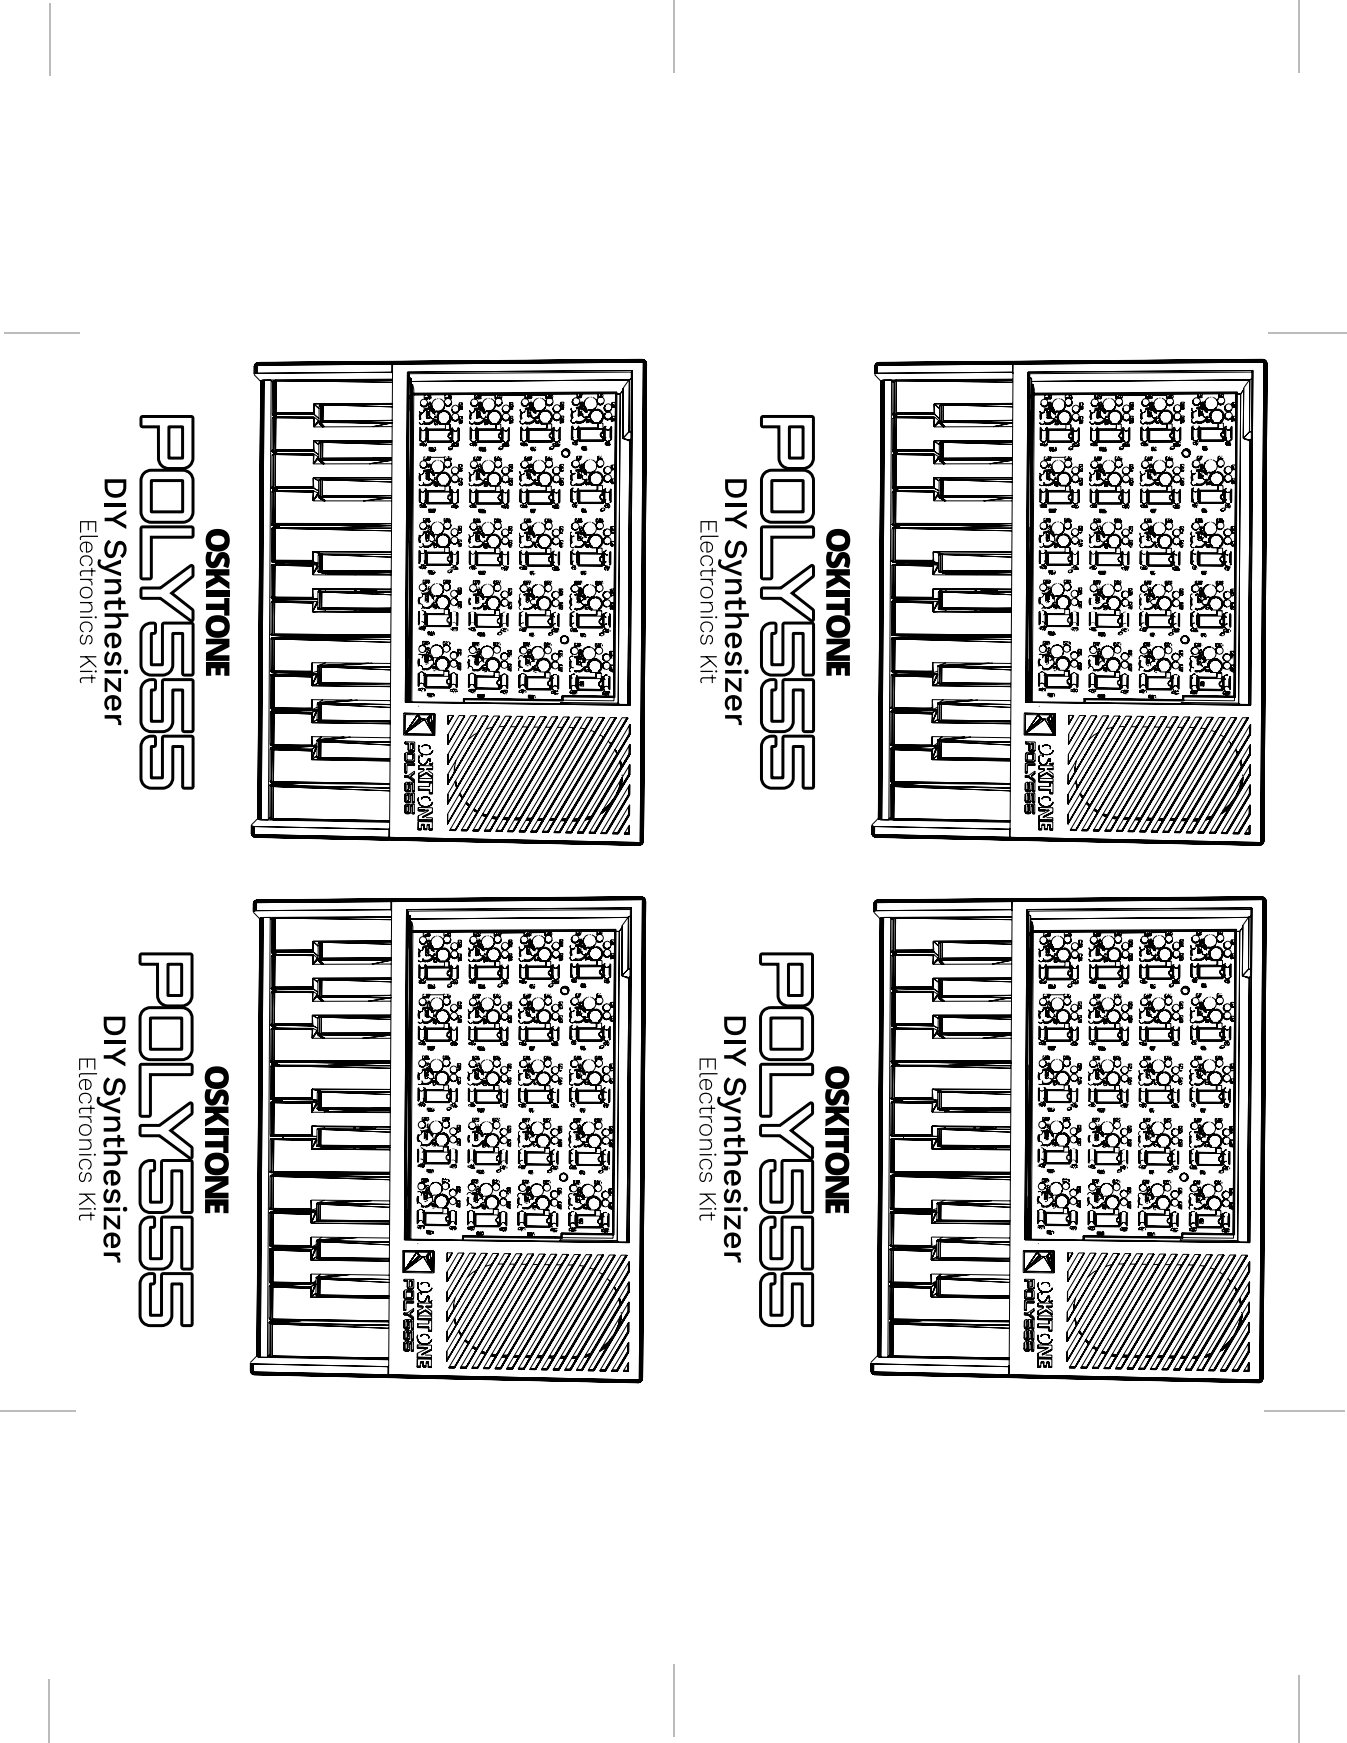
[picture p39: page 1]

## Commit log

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2020-06-25 Fixed button layout
    [555_astable.sch, poly_555.kicad_pcb, poly_555.sch]
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2020-06-30 Fix hole diam, unconnected R2
    [poly_555.kicad_pcb]
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2020-07-01 Routed and error-free
    [poly_555.kicad_pcb]
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2020-07-07 Add util function to derive natural key count
    And test a lil bit!
    [assembly.scad, tests.scad]
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2020-07-10 Swap for a flat speaker
    [assembly.scad]
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2020-07-10 Enable and define enclosure rounding $fn
    I was getting confused why the enclosure wasn't touching the Z axis
    [assembly.scad]
2020-07-12 Fix borked window cavity preview
    [assembly.scad]
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2020-07-13 Fix errant mount hole diameter
    [assembly.scad]
2020-07-13 Fix key vs battery collision
    tho TBD on DFM...
    [assembly.scad]
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2020-07-13 Try to prevent switch from getting pushed in
    [assembly.scad]
2020-07-13 Adjust tolerance on switch cavity
    From full tolerance to half for press-fit. Could actually be 0 but not
    necessary.
    Verified w/ test print
    [assembly.scad]
2020-07-13 Ensure union on clasps to enclosure
    This was an obvious problem before commit 2a5f5f5258, where a gap was
    visible between the clasps and enclosure body
2020-07-13 Add battery snap module
    Per usual, tidied and copied from OKAY
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2020-07-17 Fix speaker preview
    [assembly.scad]
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2020-07-17 Try thinner walls
    1.8 works well for jar planters so maybe will be good for these too
    [assembly.scad]
2020-07-17 Move debug intersection into module
    to use private variables in translate positions
    [assembly.scad]
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2020-07-18 Pedestal mount stilts
    I'm hopeful these will act like little ramps and make sliding nuts
    into their cavities easier
    [assembly.scad]
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2020-07-18 Temporarily increase key travel
    This is what it measures for 2mm thick keys, which had some bend. I
    expect the real travel to be lower but won't know for sure til a full
    print.
    [assembly.scad]
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2020-07-18 Make room for battery snap
    [assembly.scad]
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2020-07-22 Add mounting rail on TOP of cantilever mount
    I don't love this but I'm trying to prevent the screws' turning from
    distorting the keys' gutters. This was also a problem w/ the OKAYs.
    Anyway, this kinda seems to work but isn't 100%.
    Also has some magic in it to reduce the height arbitrarily, because the
    ideal math was just a litttle too tall and prevent lid from closing
    all the way.
    [assembly.scad]
2020-07-22 Increase and parameterize speaker clearance
    It is not really a constant like the other values
    [assembly.scad]
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2020-07-25 Reverse fine tuning rotation
    These pots are countinerintuitive
    [555_astable.sch, poly_555.sch]
2020-07-25 Fix swapped 386 POW/GND pins
    [555_astable.sch, poly_555.sch]
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2020-07-25 Re-annotate and update footprints
    * vertical resistors
    * radial, electrolytics timing caps
    * add switch
    [555_astable.sch, poly_555.sch]
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2020-07-25 Swap pot footprint
    Still not the correct component that I'm using, but this one at least
    has larger holes for its legs (instead of wire leads) which I'm hoping
    will make the pots easier to insert
    [555_astable.sch, poly_555.sch]
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2020-07-27 Re-annotate to fix key vs 555 mismatch
    The alignment of switch to 555 circuit was off, starting around S8. I
    believe this was from non-linear copy-pasting when key count jumped from
    13 to 20.
    No amound of fiddling with the annotation tool seemed to fix and to do
    it manually was out of the question, so I ended up deleting 6-20 and
    copy-pasting 1-5 three times. I think it worked...
    [555_astable.sch, poly_555.kicad_pcb, poly_555.sch]
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2020-07-27 Update labels
    * Move OSKITONE label to right by battery
    * ^ and, for now at least, remove 0.0.0 version
    * Rearrange 555 circuit labels
    * Label LED legs
    [poly_555.kicad_pcb]
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2020-07-28 Fix button alignment and its routing
    Looks like math was wrong. Good thing it was caught before sending to
    fab
    [poly_555.kicad_pcb]
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2020-07-28 Tighten bottom mounting row gap
    and simplify routing
    [poly_555.kicad_pcb]
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2020-07-29 Update assembly model for new PCB
    * Increase keys_count
    * Update mounting holes and buttons math
    * Extract keys_x
    * Drop soon-to-be-obviated battery-under-keys assertion
    [assembly.scad]
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2020-07-29 Woops, fix incorrect window pane dimensions echo
    [assembly.scad]
2020-07-29 Reposition battery into its PCB cavity
    and ditch newly unnecessary key undercarriage
    [assembly.scad]
2020-07-29 Switch to smaller speaker, repositioned beneath keys
    Reverts commit 312d436bf8
    [assembly.scad]
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2020-07-29 Revert "Switch to pushbutton switch I actually have on hand"
    This reverts commit a5fdbd226ee23176fa6426987996df6582198590.
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2020-07-31 Fix floating PCB buttons
2020-07-31 Add key hitch to assembly
    * Refine key_travel -- almost certainly still too high for its usage
    because it's measured at the key's end instead of the button's
    position... but fine for now and can be refined later
    * Extract _mounted_keys so its hitch can be used independently
    * Visualize PCB buttons to preview against hitch placement
    [assembly.scad]
2020-08-03 Refine hitch
    * Widen narrow holes so screws don't get stuck
    * Let screw heads poke out the sides to avoid model errors when
    minimum_wall is the same as tolerance
    * Try to bring back lost space from unaccounted tolerances in both the
    hitch itself and its cavity
    * Increase hitch_clearance (probably too high but can narrow later once
    tolerance is good and ready)
    * Don't let hitch_clearance affect height
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2020-08-04 Start volume thumbwheel
    Good start!
    * Uses new visualize_board PCB arg to make cavity
    * Adds ring() and cylinder_grip() (better name?) basic shape modules
    * Swaps cylinder stub for trimpot_knob in PCB module
    * Adds new trimpot_knob() module
    * Updates and extracts pot height for thumbwheel Z
    [assembly.scad]
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2020-08-04 Swap total_height->height enclosure_half arg
    This breaks and makes explicit the assumption that the two enclosure
    halves are the same height. Should allow more intuitive weighted halves.
    [assembly.scad]
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2020-08-05 Refine assembly enclosure
    * Make keys sliding onto hitch easier by dropping enclosure bottom's
    height and switching lip removal sides
    * Extend keys cavity to the entire front "bumper" of enclosure
    * And add ^ bumper to enclosure bottom
    * Remove enclosure clasp
    * Add mounting rails to enclosure top, above key mount
    [assembly.scad]
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2020-08-05 Rewrite enclosure_length to not rely solely on PCB Y
    Less brittle! Fewer things to reason about!
    [assembly.scad]
2020-08-05 fixup! Refine assembly enclosure
    [assembly.scad]
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2020-08-05 Tighten keys_back_gutter to minimum
    [assembly.scad]
2020-08-05 Fix poor hitch positioning
    Hitch was 1) too close to the end of the accidental for it to properly
    enclose on both sides and 2) too low into the key for it to catch.
    This change 1) lengthens accidentals based on measurements from my
    Hammond and 2) exposes + uses a HITCH_RECOMMENDED_MINIMUM_CAVITY_HEIGHT
    const instead of some arbitrary, key-derived thing.
    [assembly.scad]
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2020-08-06 Loosen switch cavity
    It doesn't need to be as tight because the switch will be mounted
    to the PCB.
    [assembly.scad]
2020-08-06 Differentiate top vs bottom mounting holes
    * Extend ring to take an inner_diameter
    * Add spacer_array
    * Use ^ for screws under key mount that insert thru enclosure bottom
    [assembly.scad]
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2020-08-06 Tighten enclosure height
    [assembly.scad]
2020-08-06 Flip volume wheel and correct its Z
    [assembly.scad]
2020-08-07 Adjust speaker container
    * Narrow gap to just the solder tab part
    * Tighten tolerance for a better hold
    [assembly.scad]
2020-08-10 Ensure bottom mounting screws have full closure
    and fix poor plastic bonding from super small layer overlap
    [assembly.scad]
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2020-08-10 Chamfer screw head cavities
    to prevent jagged edges on enclosure bottom
    [assembly.scad]
2020-08-10 Cheaply try to strengthen enclosure
    Because the enclosure's inner cavity isn't rounded, there was a slight
    gap in the lip's other wall where its rounded edge was cut off, and it
    was WAY too easy for it to chip off after printed.
    A proper fix would be to round the cavity and maybe increase the wall
    depth or add some other reinforcement.
    * Decreases lip (which is on the inside) so the outer part can be wider
    * Switches lip from bottom to top -- w/o the window in its cavity to
    hold the width, the top can be squeezed in because there's no lip
    there
    * Adjusts bottom height to include lip -- now that the bottom has a
    bumper that prevents easily sliding the keys onto their hitch, this
    hei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
    [assembly.scad]
2020-08-10 Reinforce hitch
    to prevent screw tightening from distorting it
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2020-08-12 Tighten hitch clearance
    Seems okay on test print
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2020-08-12 Tighten nut lock heights
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2020-08-14 Give hitch screws more room
    Not ideal but fine for now, until I have longer screws or enclosure/height is taller
    [assembly.scad]
2020-08-14 Fix mounting rail feet collision w/ PCB
    [assembly.scad]
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2020-08-21 Start new PCB layout
    * wider cavity w/o top
    * swap fine trimmer for resistor
    * bigger wire holes for speaker,battery
    * 5mm LEDs
    [555_astable.sch, poly_555.kicad_pcb, poly_555.sch]
2020-08-22 Fix rail aligner from obstructing top
    [assembly.scad]
2020-08-22 IDR but maybe fixup for PCB relayout
    [poly_555.kicad_pcb]
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2020-08-24 fixup! Update PCB model
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2020-08-28 Fix and derive volume wheel diameter
    [assembly.scad]
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2020-08-30 Swap to rectangular speaker and fit into side panel
    With plenty of refactoringgggg
    [assembly.scad]
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2020-08-31 Add screw mounting holes for speaker
    Necessitates increasing the depth up there to account for screw heads
    [assembly.scad]
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2020-09-02 Fix and tidy tolerance usage in enclosure lip
    Previously was some fraction of what was provided, which was confusing
    and inconsistent with tolerance usages elsewhere.
    Added a lil debugger too
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2020-09-04 Fix errant indentation
    [assembly.scad]
2020-09-04 Rewrite enclosure top's bumper
    Not really less code but, I think, more intuitive
    [assembly.scad]
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2020-09-09 Rework branding on top
    * Derive font sizes
    * Try to use full real estate
    * Switch to Orbitron font for model name
    [assembly.scad]
2020-09-10 Rewrite window pane math
    * Ditch window pane color/opacity, which did nothing good
    * Rename variables to differentiate between the window pane of glass vs
    window cavity
    * There's only one "window", so no need to qualify it as the "PCB..."
    * Add lengthwise cross-section
    [assembly.scad]
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2020-09-10 Rewrite speaker container
    * Try to use less plastic
    * No need to hold up from both magnet AND cone bottom, use only latter
    * Experiment with open bottom design
    [assembly.scad]
2020-09-11 Refine battery measurements and tolerance fit
    based on all the 9vs I happen to have on hand
    Was hoping it'd make enclosure shorter but fraid not. Tho does make
    the holder tighter
    [assembly.scad]
2020-09-11 Decouple Z clearances
    and remove a vestigial one
    [assembly.scad]
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2020-09-11 Animate plastics tolerance
    to visualize full range of fits
    [assembly.scad]
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2020-09-23 Improve window pane support strut
    * Decrease from 2 to 1, which will strain plastic less on install
    * Make width less arbitrary
    * Decrease length overlap but tighten on Z
    [assembly.scad]
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2020-09-26 Refine key_mounting_rail
    Ditches big mounting_rail for a custom job
    * Differentiate between the newly narrowed wall, the nut lock rail, and
    the window pane sill
    * Add DFM supports to window sill
    * Shorten screw cavities to sill
    * Narrow non-structural pane alignment rail
    * Ensure rail and enclosure lip don't collide
    [assembly.scad]
2020-09-26 Refine window_pane_bottom_supports
    * Reduce from 3 to 2
    * Straddle strut
    * Fix obstructions on strut and enclosure lip
    [assembly.scad]
2020-09-27 Widen keybed cavity
    Previously, it was just a smidge too tight when installing the PCB
    [assembly.scad]
2020-09-27 Shorten (and rename) pane stilts
    Again, to give PCB more room in assembly
    [assembly.scad]
2020-09-27 Ditch aligner feet on mounting rail
    These are too small to print and don't do much anyway
    [assembly.scad]
2020-09-27 Align keys mount
    * Extract key_mounting_rail_x
    * Ditch original keys mount for mounting_rail
    * Lengthen mounting_rail_aligners to full enclosure half height
    * Tidy _mounting_rails
    [assembly.scad]
2020-09-27 Tighten speaker container
    and simplify connected battery container
    [assembly.scad]
2020-09-27 Loosen volume wheel enclosure cavity
    [assembly.scad]
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2020-09-28 Move volume wheel "flank" wheel enclosure side
    This is the section of the wall+lip between the key mounting rail
    and the volume wheel cavity. It's not hard to print but, because it's
    small and separate from the other walls, it can kinda spill over and
    obstruct the key mounting rail on the other enclosure side.
    [assembly.scad]
2020-09-29 Try tightening key_mounting_rail nut locks
    [assembly.scad]
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2020-09-29 Fix mount_stilt nut lock misalignment
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2020-09-30 Tighten key mounting rail nut lock floor
    [assembly.scad]
2020-09-30 Fix volume wheel brace Z
    This explains why it was so tight before!
    [assembly.scad]
2020-10-02 Fix mounting rail aligners vs enc lip obstruction
    [assembly.scad]
2020-10-15 Stilt under volume wheel pot
    Provides counter force when applying volume wheel
    [assembly.scad]
2020-10-15 Fix volume wheel cavity Z
    Previously didn't account for the pot cap height
    [assembly.scad]
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2020-10-15 PCB revisions:
    * Add voltage regulator to POLY_555
    * Ditch hitch
    * Reorder switches+circuits left to right
    * Carve out room for battery
    * Mark # 555s
    * Label wired pins better
    APC updates:
    * Fix ground error
    * Reverse volume pot direction
    * Swap timing cap footprint
    * Add stress relief hole for battery wires
    * Widen speaker pins
    [555_astable.sch, apc.sch, poly_555.kicad_pcb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]
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2020-10-15 Reverse dovetail hitch mount wall side
    This way, the PCB holds the hitch into place
2020-10-17 Increase key cantilever mount height
    Will hopefully prevent screw tightening from affecting key action
    [assembly.scad]
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2020-10-25 Update PCB
    * Fix and expand battery cavity
    * Fix S13-S20,C61,U21 label placements
    * Fix uneven breakaway wall near APC
    * Swap misplaced C62,R83 labels
    * Assign C103 value
    * Swap 4.7uF cap footprints and re-route
    * Move LED
    * Upgrade APC pots
    * Move to 0,0
    * Expand battery cavity even more
    * Update branding: ditch _ and space, add rev, add to back side too
    * Add APC rev too
    [555_astable.sch, apc.sch, poly_555.kicad_pcb]
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2020-11-02 Add script to export individual STLs
    And parameterize echoing out dimensions to reduce noise
    [assembly.scad, config.scad]
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2020-11-09 Increase enclosure_bottom_height to top of volume wheel
    IDKY it wasn't like this before!
    * Ditch now unnecessary "flank wall" idea
    * Remake volume wheel cavity for extra height and simplify _pcb()
    * Adjust rail clearance
    [assembly.scad]
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2020-11-09 Increase switch clearance
    [assembly.scad]
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2020-11-09 Tighten window pane strut fit
    [assembly.scad]
2020-11-09 Hack down speaker container height
    Either math or measurements were off somewhere, because it's
    too tall
    [assembly.scad]
2020-11-09 Hitch enclosure back with window pane stilts
    * Pull out _window_pane_stilts to _hitch_stilts for cavity usage
    * Ditch tongue and groove
    * Parameterize enclosure lip stuff and add small clearance
    * Brittly de-obstruct window pane strut from hitch stilts
    * New cross section for test prints
    [assembly.scad]
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2020-11-14 Update PCB and schematic
    * Finalize timing R to 100
    * Drop LED ohms to 220
    * Add missing 1k value to RV21
    * Fix timing cap and 7805 label placements
    * Widen speaker and battery relief holes
    * Re-label SPK and BAT
    [555_astable.sch, poly_555.kicad_pcb, poly_555.sch]
2020-11-14 Bring back U5 label placement
    The fabbed PCB has this IN the chip footprint but somehow
    that wasn't commited.
    I HOPE that's the only thing I lost.
    [poly_555.kicad_pcb]
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2020-11-17 Improve minor PCB+ visualizations
    * Don't show circuit space w/o PCB board
    * Simplify volume wheel for quick preview
    [assembly.scad]
2020-11-17 Improve make_stls.sh
    * Add commit hash to folder and filename for extra uniqueness
    * Flip STLs for 3D printer
    * Fix errant switch showing up for volume wheel
    * Prevent window pane from ever showing
    * Ditch vestigial SHOW_HITCH config
    [assembly.scad, config.scad]
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2020-11-22 Try looser speaker fit
    [assembly.scad]
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2020-11-22 Minimize volume wheel brace
    And prevent potential obstruction with enclosure lip
    [assembly.scad]
2020-11-22 Rethink window pane struts
    * Try cube instead of triangle prism thing
    * Add breakaway supports now that we don't have 45deg angles
    * Narrow for fewer supports
    * Add side strut too
    [assembly.scad]
2020-11-22 Refine LED exposure
    * Reduce wall thickness since it's non-structural
    * But add gusset just in case
    * Remove vestigial difference()
    [assembly.scad]
2020-11-22 Fix hitch cavity support bridge
    [assembly.scad]
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2020-11-25 Fix uneven volume wheel cavity height
    [assembly.scad]
2020-11-25 Reinforce volume wheel brace
    * Switch to full height rib instead of partial height gusset
    * Increase ^ to fully available height
    * Parameterize and increase cone diameter
    [assembly.scad]
2020-11-25 Try to support window pane on the right
    It's possible this isn't great because there won't be enough give to
    bend and allow the pane to get in there. Worth a try tho.
    [assembly.scad]
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2020-11-30 Reduce vol wheel exposure
    Trying to cheaply fix disappearing wall there
    [assembly.scad]
2020-12-03 Refine volume wheel brace
    * Bring back narrower cone diameter to prevent collisions with speaker
    * Add just a lil clearance so it's easier to turn
    [assembly.scad]
2020-12-06 Tidy schematic
    * Remove vestigial comments
    * Fix odd 555 sheet name
    [555_astable.sch, poly_555.sch]
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2021-01-20 Address Sebastian's feedback
    * Explain lack of printed guide
    * Improve 7805 soldering instructions
    * Warn against bent/missing socket legs
    * Advise to wash hands after finishing soldering
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2021-02-15 Color mounting rail to match enclosure
    And ditch vestigial TODO while I'm in there
    [assembly.scad]
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2021-02-19 Update APC vol from 5k to 1k
    Cuz that's what I got!
    [apc.sch, poly_555.kicad_pcb]
2021-04-30 Work around intersection() bug in OpenSCAD 2021.01
    I thought this looked familiar!
    https://github.com/oskitone/apc/commit/32edc9fdb3968f4e2595d344c7c22e29c5d84470
    [poly555.scad]
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2021-05-07 Um, fix overloaded engraving size arg
    [poly555.scad]
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2021-05-18 Tidy BOM
    * Sort documentation BOM and reduce 100ohm resistors (thanks Nick!)
    * Remove git-ignored bom.csv so ^ is canonical
    [bom.csv]
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2021-07-09 Improve pencil_stand
    * Add tightening webs to grip utensils better
    * Chamfer entrance
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2021-09-14 Fix reduced_test_case cross_section
    [poly555.scad]
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2021-11-02 It's okay if the volume wheel is a little loose
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2022-01-24 Fix broken relative docs links
    When URL has a trailing slash (ex: /poly555/pcb-1/ instead of
    /scout/general-tips), relative links assume nested folder
    (ex: /poly555/pcb-1/pcb-0#leds instead of the desired
    /poly555/pcb-0/#leds).
    One fix is to remove the trailing slash:
    https://docusaurus.io/docs/api/docusaurus-config#trailing-slash
    Another is to link to the source markdown file instead of using a
    generic relative link. This has some nice advantages around linking
    in Github and versioning:
    https://docusaurus.io/docs/docs-markdown-features#referencing-other-documents
    (This commit is the same as Scout's a9a526c6cf)
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2022-07-16 Advise on battery replacement in Care
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2024-11-08 Update key sleeve
    * Make it a reference for folder tool, not print
    * Make square so there's no wrong orientation
    * Ditch PDF
